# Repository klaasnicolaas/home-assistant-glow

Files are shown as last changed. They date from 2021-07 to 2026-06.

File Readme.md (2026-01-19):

# Home Assistant Glow 🌟

<!-- PROJECT SHIELDS -->

[](LICENSE)
[][forks-url]
[][stars-url]
[][issues-url]

[][commits]
[][commits]
[][contributors-url]

During my internship at [Nabu Casa][nc] in the first half of 2021, I focused on energy management for your house, how to collect all energy data and display it on a dashboard. Since Home Assistant release **2021.8** it's possible to use the [Home Assistant Energy][energy] dashboard to display your energy usage. Unfortunately, not everyone has a smart meter and/or is equipped with a P1 port. This is where the Home Assistant Glow comes in!

<p align="center">
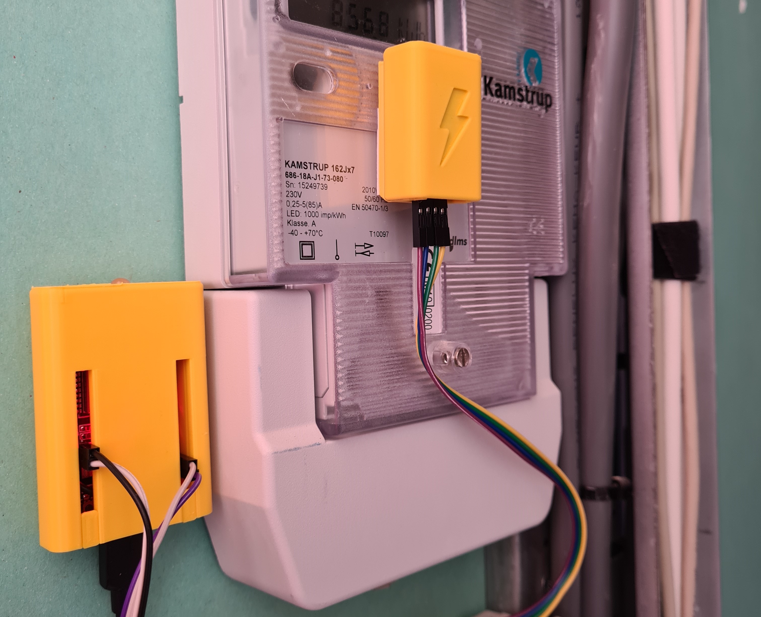
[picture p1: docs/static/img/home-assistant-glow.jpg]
  
</p>

<details>
  <summary>CLICK HERE! To see the Home Assistant Glow in action.</summary>

  <p align="center">
    Glow testingGlow in action
  </p>
</details>

Home Assistant Glow makes a *(not so)* smart meter without a P1 port easily readable, reading the pulse LED that is always present in most cases and it works with [ESPHome][esphome]! To neatly hide it all in your meter cupboard, a case has been designed that you can 3D print yourself.

### How do I know if my meter is supported?

To make sure your meter will work with the Home Assistant Glow, you have to look for the `imp/kWh` rate on your meter (see picture). Make a note of this value because you may need it later when configuring your device.

<p align="center">
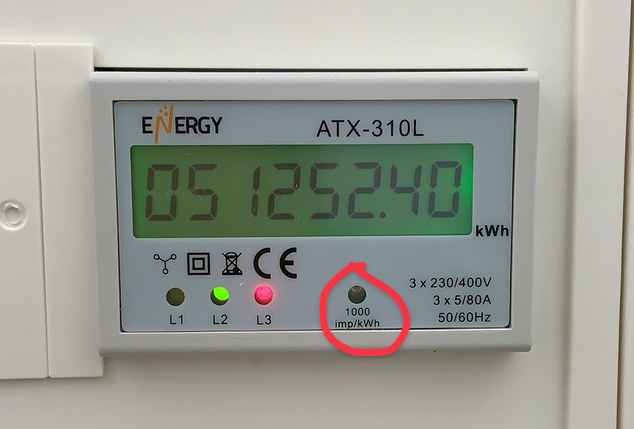
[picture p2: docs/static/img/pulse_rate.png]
  
</p>

## Getting Started

> [!IMPORTANT]
> Please note, the default branch shows development and may be ahead of the released version. For copying YAML code, use the [release branch](https://github.com/klaasnicolaas/home-assistant-glow/releases/latest). It's best to use the [website](https://glow-energy.io/docs/getting-started#step-2---install-firmware) to install the latest firmware on your ESP.

On the [documentation website](https://glow-energy.io/docs/introduction) you will find a complete walkthrough with which hardware you need, how to install the correct firmware on your ESP (using esp web tools) and how to add it to Home Assistant.

## Hardware

First, fill your 🛒 or see if you already have the components below.

Choose one of the listed microcontrollers, but keep in mind that the ESP32 is recommended.

  - ESP32 (recommended) - [AliExpress](https://s.click.aliexpress.com/e/_DdAe4Fl) or [Banggood][esp32-bg-shop] or [AliExpress][esp32-ali-shop]
  - ESP32-C3 - [AliExpress](https://s.click.aliexpress.com/e/_DFNCxYn) or [AliExpress][esp32c3-ali-shop]
  - ESP8266 - [AliExpress](https://s.click.aliexpress.com/e/_omR3PTr) or [Banggood][esp8266-bg-shop] or [AliExpress][esp8266-ali-shop]
- Dupont Jumpers (female to female) - [AliExpress](https://s.click.aliexpress.com/e/_DmbrJsj) or [Banggood][dupont-jumpers-shop]
- 3D-printed case (see the [case](https://glow-energy.io/docs/resources/cases) folder)
- LM393 Photodiode: [AliExpress](https://s.click.aliexpress.com/e/_c3utxSRp) or [Banggood][photodiode-bg-shop] or [AliExpress][photodiode-ali-shop] (please note that you will not receive an LDR)
- LED RGB 5mm 4 pin - kathode: [AliExpress](https://s.click.aliexpress.com/e/_c3H3JVT9) or [Banggood][rgbled-bg-shop] or [AliExpress][rgbled-ali-shop]

## Contributing

We welcome contributions! Please read the [contribution guidelines](CONTRIBUTING.md) before submitting PRs.

Thanks to everyone who already contributed! ❤️

<a href="https://github.com/klaasnicolaas/home-assistant-glow/graphs/contributors">
  
</a>

For a full list of all authors and contributors, check [the contributor's page][contributors-url].

## Disclamer

Affiliate links are used on this repository to support the Home Assistant Glow 🌟 project. Some Ad-blockers might block these links and thus they seem to appear broken. You will have to temporarily disable ad-blocker to open these links.

## License

MIT License

Copyright (c) 2021-2026 Klaas Schoute

Permission is hereby granted, free of charge, to any person obtaining a copy
of this software and associated documentation files (the "Software"), to deal
in the Software without restriction, including without limitation the rights
to use, copy, modify, merge, publish, distribute, sublicense, and/or sell
copies of the Software, and to permit persons to whom the Software is
furnished to do so, subject to the following conditions:

The above copyright notice and this permission notice shall be included in all
copies or substantial portions of the Software.

THE SOFTWARE IS PROVIDED "AS IS", WITHOUT WARRANTY OF ANY KIND, EXPRESS OR
IMPLIED, INCLUDING BUT NOT LIMITED TO THE WARRANTIES OF MERCHANTABILITY,
FITNESS FOR A PARTICULAR PURPOSE AND NONINFRINGEMENT. IN NO EVENT SHALL THE
AUTHORS OR COPYRIGHT HOLDERS BE LIABLE FOR ANY CLAIM, DAMAGES OR OTHER
LIABILITY, WHETHER IN AN ACTION OF CONTRACT, TORT OR OTHERWISE, ARISING FROM,
OUT OF OR IN CONNECTION WITH THE SOFTWARE OR THE USE OR OTHER DEALINGS IN THE
SOFTWARE.

<!-- MARKDOWN LINKS & IMAGES -->
[esphome]: https://esphome.io
[nc]: https://www.nabucasa.com
[energy]: https://www.home-assistant.io/home-energy-management

<!-- Shields -->
[maintenance-shield]: https://img.shields.io/maintenance/yes/2026.svg
[contributors-shield]: https://img.shields.io/github/contributors/klaasnicolaas/home-assistant-glow.svg
[contributors-url]: https://github.com/klaasnicolaas/home-assistant-glow/graphs/contributors
[forks-shield]: https://img.shields.io/github/forks/klaasnicolaas/home-assistant-glow.svg
[forks-url]: https://github.com/klaasnicolaas/home-assistant-glow/network/members
[stars-shield]: https://img.shields.io/github/stars/klaasnicolaas/home-assistant-glow.svg
[stars-url]: https://github.com/klaasnicolaas/home-assistant-glow/stargazers
[issues-shield]: https://img.shields.io/github/issues/klaasnicolaas/home-assistant-glow.svg
[issues-url]: https://github.com/klaasnicolaas/home-assistant-glow/issues
[license-shield]: https://img.shields.io/github/license/klaasnicolaas/home-assistant-glow.svg
[commits-shield]: https://img.shields.io/github/commit-activity/y/klaasnicolaas/home-assistant-glow.svg
[commits]: https://github.com/klaasnicolaas/home-assistant-glow/commits/main
[last-commit-shield]: https://img.shields.io/github/last-commit/klaasnicolaas/home-assistant-glow.svg

<!-- Hardware -->
[esp32-bg-shop]: https://www.banggood.com/bang/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
[esp32-ali-shop]: https://tc.tradetracker.net/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
[esp32c3-ali-shop]: https://tc.tradetracker.net/?c=15640&m=12&a=417111&r=&u=%2Fitem%2F1005006391993583.html
[esp8266-bg-shop]: https://www.banggood.com/bang/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
[esp8266-ali-shop]: https://tc.tradetracker.net/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
[dupont-jumpers-shop]: https://www.banggood.com/bang/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
[photodiode-bg-shop]: https://www.banggood.com/bang/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
[photodiode-ali-shop]: https://tc.tradetracker.net/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
[rgbled-bg-shop]: https://www.banggood.com/bang/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
[rgbled-ali-shop]: https://tc.tradetracker.net/?c=15640&m=12&a=417111&r=&u=%2Fitem%2F4000225253691.html

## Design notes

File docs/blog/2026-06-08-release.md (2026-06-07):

---
slug: release-5.0.0
title: Release 5.0.0
authors: klaas
tags: [glow, release, update]
---

Version 5.0.0 of the Home Assistant Glow is here 🌟! This major release brings a configurable internal filter to reduce ghost pulse detections, alongside a **breaking change**: all entity names have been cleaned up to follow the modern ESPHome naming convention.

<!-- truncate -->

## Entity Name Changes

ESPHome now recommends using bare entity names without a device name prefix. Home Assistant automatically shows entity names in the context of their device, making the prefix redundant. All entities in the Glow firmware have been updated accordingly.

The following entities have been renamed:

| Old name | New name |
|---|---|
| `{device} - Power Consumption` | `Power Consumption` |
| `{device} - Total Energy` | `Total Energy` |
| `{device} - Daily Energy` | `Daily Energy` |
| `{device} - ESPHome Version` | `ESPHome Version` |
| `{device} - IP Address` | `IP Address` |
| `{device} - Connected SSID` | `Connected SSID` |
| `{device} - WiFi Signal` | `WiFi Signal` |
| `Glow - Installed version` | `Installed Version` |
| `Restart - Glow` | `Restart` |

:::warning Breaking change
Renaming entities changes their entity IDs in Home Assistant. After updating, the old entities will show as unavailable and new ones will be created. You will need to update any automation flows, dashboards, or Energy dashboard configurations that reference the old entity IDs.
:::

### Migration Guide

After updating to 5.0.0, take the following steps:

1. Open Home Assistant and go to **Settings > Devices & Services > ESPHome**
2. Open the Glow device page and verify the new entity names appear
3. Remove the unavailable (old) entities via **Settings > Devices & Services**, selecting each old entity and deleting it
4. Update any automation flows or dashboard cards that referenced the old entity IDs
5. If you use the Energy dashboard, re-select the correct entities under **Settings > Energy**

## Configurable Internal Filter

Based on a [community request][issue-983], this release exposes the internal filter of the pulse meter as a configurable entity in Home Assistant. Previously, users experiencing ghost pulses (false detections that cause unrealistic power spikes) had no way to adjust the filter without modifying the firmware directly.

The **Internal Filter** entity appears in the configuration section of the Glow device page in Home Assistant. It accepts values in microseconds (µs), with a default of `1000 µs` (1 ms) and a maximum of `100000 µs` (100 ms). The value is persisted across reboots, so you only need to set it once.

If you are experiencing sudden power spikes in the thousands of kilowatts, try increasing the internal filter value gradually. A value between **1000 µs** and **10000 µs** is a good starting point for most setups.

:::caution
Setting the internal filter too high can cause real pulses to be missed at high power consumption. See the [Internal Filter](/docs/configuration/internal_filter) page for guidance on choosing the right value for your setup.
:::

:::note Upgrade note for advanced users
If you previously used `!extend sensor_energy_pulse_meter` with `internal_filter` in your YAML configuration, this will no longer have any effect. The **Internal Filter** entity always takes precedence after boot. You can remove the `!extend` block and set your desired value via the UI instead.
:::

## Pulse Rate Entity Fix

ESPHome warns that entity names containing `/` are reserved as URL path separators and will become an error in ESPHome 2026.7.0. The **Pulse Rate** entity was previously named `Pulse rate - imp/kWh` and is now simply `Pulse rate`, with `imp/kWh` set as a proper `unit_of_measurement`.

## Upgrading to 5.0.0

**Via Home Assistant**: If your Glow is connected to Home Assistant, you'll receive an update notification automatically. Simply click update from the device page, the easiest option.

**Via the Web Interface (OTA)**: Download the correct firmware binary from the [Firmware Updates](/docs/advanced/firmware_updates) page, open the Glow's web interface, and upload it via the **OTA Update** section.

**Via USB**: Head to the [Getting Started](/docs/getting-started) page, select your variant, and flash via USB.

## Wrap up

This release is a significant step in keeping the Home Assistant Glow aligned with current ESPHome best practices, while also making the firmware easier to use for those dealing with noisy meter environments. The entity renaming requires some manual steps after upgrading, but the result is a cleaner and more consistent device experience in Home Assistant.

If you would like to support the project, you can do so through [GitHub sponsors](https://github.com/sponsors/klaasnicolaas) or Ko-fi. If you have any questions, you can ask them via the [discussions](https://github.com/klaasnicolaas/home-assistant-glow/discussions), and if you encounter problems with the Home Assistant Glow, you can indicate this in the [issues](https://github.com/klaasnicolaas/home-assistant-glow/issues).

./Klaas



## Related links

- [Internal Filter Configuration](/docs/configuration/internal_filter)
- [FAQ: Unrealistic power spikes](/docs/faq/ghost_pulses)
- [Customizing the Firmware](/docs/advanced/firmware_changes)
- [Firmware Updates](/docs/advanced/firmware_updates)

<!-- Links -->
[issue-983]: https://github.com/klaasnicolaas/home-assistant-glow/issues/983

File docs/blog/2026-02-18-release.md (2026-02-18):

---
slug: release-4.4.0
title: Release 4.4.0
authors: klaas
tags: [glow, release, update]
---

Version 4.4.0 of the Home Assistant Glow is here 🌟! The highlight of this release is the **Glow Basic** variant, a firmware for setups without LED hardware, alongside improved GitHub Actions workflows and a refreshed documentation experience.

<!-- truncate -->

## Glow Basic Variant

Based on a [community request][discussion-910], this release introduces **Glow Basic**: a firmware variant without LED support. For setups where the Glow sits in a closed meter cabinet or where the LED hardware simply isn't wired up, there was no clean way to run the firmware without unnecessary LED-related log entries. Glow Basic solves that.

- **Lighter firmware**: No LED components are included, resulting in a smaller and simpler build
- **Separate device identity**: Shows up as `Glow Basic` in Home Assistant, making it easy to distinguish from the standard variant
- **Same core functionality**: Pulse meter, energy tracking, OTA updates, and web server all work the same

Available for all three supported boards: ESP32, ESP32-C3, and ESP8266.

### Choosing Your Variant

The [Getting Started](/docs/getting-started) page now features an interactive firmware selector to pick between **Standard** and **Basic** before flashing your device.

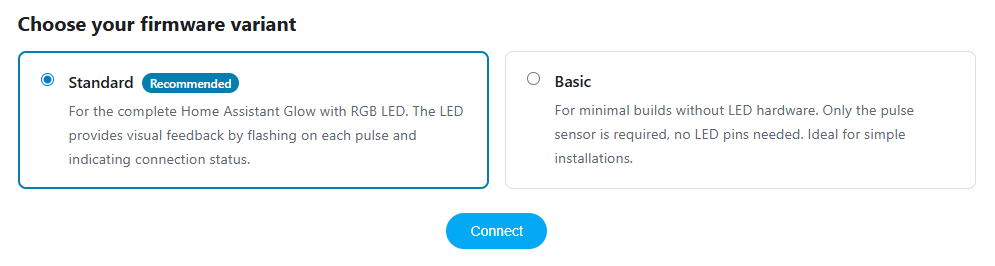
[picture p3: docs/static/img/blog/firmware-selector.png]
Firmware Selector


## Improved Build & Deploy Workflows

The GitHub Actions workflows have been updated to support both firmware variants through a matrix build strategy:

- **Matrix builds**: Each pull request and release now builds firmware for all device and variant combinations in parallel
- **Organized artifacts**: Build artifacts follow a clear naming scheme (`build-glow-standard-esp32`, `build-glow-basic-esp32c3`, etc.)
- **PR download table**: Pull request comments now include a table with download links for both variants, making it easy to test firmware from any PR

## Documentation Improvements

The getting started guide received a visual overhaul:

- **Step badges**: Each step now has a numbered badge for clearer visual guidance
- **Firmware selector component**: An interactive radio button card to choose between Standard and Basic before connecting
- **Tabbed connection options**: Step 3 now uses tabs to present the different connection methods (auto-discovery vs manual configuration)

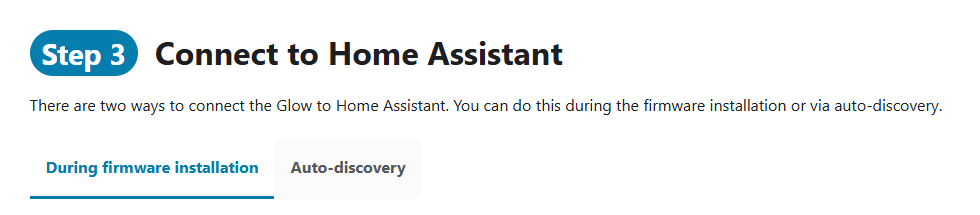
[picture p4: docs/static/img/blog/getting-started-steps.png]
Getting Started


## Upgrading to 4.4.0

There are several ways to update your Glow to the latest version:

- **Via Home Assistant**: If your Glow is connected to Home Assistant, you'll receive an update notification automatically. Simply click update from the device page — the easiest option.
- **Via the Web Interface (OTA)**: Download the correct firmware binary from the [Firmware Updates](/docs/advanced/firmware_updates) page, open the Glow's web interface, and upload it via the **OTA Update** section.
- **Via USB**: Head to the [Getting Started](/docs/getting-started) page, select your variant, and flash via USB.

:::tip Switching variants
You can switch from Standard to Basic (or vice versa) by simply flashing the other variant. Your Wi-Fi credentials and Home Assistant connection will be preserved.
:::

## Wrap up

This release makes the Home Assistant Glow more accessible by offering a basic variant for builds without LED hardware, while improving the development workflow and documentation along the way.

If you would like to support the project, you can do so through [GitHub sponsors](https://github.com/sponsors/klaasnicolaas) or Ko-fi. If you have any questions, you can ask them via the [discussions](https://github.com/klaasnicolaas/home-assistant-glow/discussions), and if you encounter problems with the Home Assistant Glow, you can indicate this in the [issues](https://github.com/klaasnicolaas/home-assistant-glow/issues).

./Klaas



## Related links

- [Getting Started Guide](/docs/getting-started)
- [Firmware Updates](/docs/advanced/firmware_updates)
- [Customizing the Firmware](/docs/advanced/firmware_changes)

<!-- Links -->
[discussion-910]: https://github.com/klaasnicolaas/home-assistant-glow/discussions/910

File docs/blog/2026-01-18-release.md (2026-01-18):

---
slug: release-4.3.0
title: Release 4.3.0
authors: klaas
tags: [glow, release, update]
---

I'm excited to announce the release of version 4.3.0 of the Home Assistant Glow 🌟. This release brings support for the ESP32-C3 board, enhanced ESP32 configurations, comprehensive documentation improvements, and a refined development workflow with linting.

<!-- truncate -->

## ESP32-C3 Support

The Home Assistant Glow now officially supports the ESP32-C3 board! This compact and energy-efficient variant of the ESP32 family is now available as a configuration option.

If you're building your own Glow or looking to upgrade, the ESP32-C3 is now a fully supported option alongside the existing ESP32 and ESP8266 boards.

:::tip 3D Case Designs Welcome
If you've designed a 3D-printed case for the ESP32-C3 variant, we'd love to add it to our [3D Cases resource page](/docs/resources/cases)! Feel free to share your design via a [discussion](https://github.com/klaasnicolaas/home-assistant-glow/discussions) or [pull request](https://github.com/klaasnicolaas/home-assistant-glow/pulls).
:::

## ESP32 Configuration Updates

The ESP32 configuration has received significant improvements in this release:

- **ESP-IDF Framework**: The ESP32 build now uses the esp-idf framework instead of arduino, providing better performance and more stability
- **Board Variant Support**: Proper board variant configuration has been added for better hardware compatibility

These changes ensure that your ESP32-based Glow device runs more efficiently and reliably.

## Documentation Overhaul

We've made extensive improvements to the documentation to help you get the most out of your Glow device:

### New Content

- **Reverting to Default Firmware**: Complete guide on how to return to the default firmware if you've adopted your device in ESPHome Builder
- **Finding Component IDs**: Documentation listing commonly used component IDs (like `sensor_energy_pulse_meter`, `status_led`, `ota_esphome`) to help you customize your device
- **Avoiding Encryption Key Issues**: New FAQ section explaining when to stick with default firmware vs. when to adopt in ESPHome Builder

### Improved Page Structure

The documentation structure has been refined to make it easier to find the information you need:

- **Getting Started**: Streamlined onboarding process with clearer step-by-step instructions
- **Advanced Sections**: Firmware updates and customization guides now have better organization with dedicated sections for different use cases
- **FAQ Pages**: Updated with practical solutions and cross-references to related documentation

## Pulse Rate Configuration

The pulse rate configuration has been adjusted for better usability:
- Minimum value changed to 10 (from lower values)
- Step size set to 10 for easier selection

This makes it simpler to configure the pulse rate for common energy meters.

## Wrap up

This release focuses on expanding hardware support and making the documentation more accessible and helpful. Whether you're setting up a new Glow device or customizing an existing one, the improved documentation should make the process much smoother.

If you would like to support the project, you can do so through [GitHub sponsors](https://github.com/sponsors/klaasnicolaas) or Ko-fi. If you have any questions, you can ask them via the [discussions](https://github.com/klaasnicolaas/home-assistant-glow/discussions), and if you encounter problems with the Home Assistant Glow, you can indicate this in the [issues](https://github.com/klaasnicolaas/home-assistant-glow/issues).

./Klaas



## Related links

- [Customizing the Firmware](/docs/advanced/firmware_changes)
- [FAQ: Encryption Key Required](/docs/faq/encryption_key_required)
- [Getting Started Guide](/docs/getting-started)

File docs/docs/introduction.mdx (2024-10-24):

---
id: introduction
title: Introduction
description: What is the Home Assistant Glow?s
---

# Introduction

During my internship at [Nabu Casa](https://www.nabucasa.com) in the first half of 2021, I focused on energy management for your house, how to collect all energy data and display it on a dashboard. Since Home Assistant release **2021.8** it's possible to use the [Home Assistant Energy](https://www.home-assistant.io/home-energy-management) dashboard to display your energy usage. Unfortunately, not everyone has a smart meter and/or is equipped with a P1 port. This is where the Home Assistant Glow comes in!

## What does it do?

Home Assistant Glow makes a (not so) smart meter without a P1 port easily readable, using the pulse LED that is always present in most cases and it works with [ESPHome](https://esphome.io)! To neatly hide it all in your meter cupboard, a case has been designed that you can 3D print yourself.

<p align="center">
  
</p>

## How do I know if my meter is supported?

To make sure your meter will work with the Home Assistant Glow, you have to look for the `imp/kWh` rate on your meter (see picture). Make a note of this value because you may need it later when configuring your device.

<p align="center">
  
</p>

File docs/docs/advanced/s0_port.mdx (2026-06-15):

---
id: s0_port
title: Using an S0 Port
description: Learn how to connect and configure the Home Assistant Glow with an S0 pulse output instead of an optical sensor.
---

# Using an S0 Port

The Home Assistant Glow is primarily designed to read the **optical pulse LED** on your electricity meter. However, some meters (particularly industrial or three-phase meters) do not have a visible pulse LED but instead provide an **S0 port** (defined in IEC 62053-31). This page explains how to connect the Glow to an S0 port and what to keep in mind.

:::caution
S0 port support is not a primary use case of the Home Assistant Glow. The hardware and default settings are optimised for optical pulse detection. The steps below describe a community-supported approach that requires some manual configuration.
:::

## What is an S0 Port?

An S0 port is an open-collector (or open-drain) pulse output. Each pulse represents a fixed amount of energy consumed, for example one pulse per Wh at 1000 imp/kWh. The port works by briefly pulling the signal line LOW for at least 30 ms, then releasing it.

Key S0 specifications (IEC 62053-31):

| Parameter | Minimum |
|---|---|
| Pulse ON time (LOW) | 30 ms |
| Pulse OFF time (HIGH) | 30 ms |

## Wiring

To connect an S0 port to the Glow, you need an external **pull-up resistor** between the pulse pin and 3.3 V, because the S0 output can only pull the line LOW and cannot drive it HIGH.

Connect the wires as follows:

| S0 Terminal | ESP32 | ESP32-C3 | ESP8266 |
|---|---|---|---|
| S0+ | GPIO26 | GPIO10 | GPIO13 |
| S0- | GND | GND | GND |

Add a **4.7 kΩ to 10 kΩ** pull-up resistor between the pulse input pin and 3.3 V. A lower resistance (e.g. 4.7 kΩ) provides better noise immunity on longer cable runs.

:::important
The ESP32, ESP32-C3, and ESP8266 all use 3.3 V logic levels. Never connect an S0 port that operates at 5 V or higher directly to a GPIO pin.
:::

## Adjusting the Internal Filter

S0 connections can be susceptible to electrical noise, particularly with long cable runs or nearby switching equipment. With the default internal filter of **1000 µs** (1 ms), noise spikes between 1 ms and 30 ms can be counted as valid pulses, causing the total energy reading to drift higher than the actual meter over time.

To reduce this effect, increase the internal filter. The internal filter defines the minimum time the signal must be active (LOW) before it is counted as a valid pulse. Per IEC 62053-31, the minimum S0 pulse ON time is 30 ms, so any filter value above that risks dropping valid pulses depending on your meter.

A value of **50000 µs** (50 ms) has been reported to produce accurate readings in practice, but this depends on your meter sending pulses longer than 50 ms. If you notice pulses being missed, lower the filter and check your meter's documentation for the actual pulse duration.

See the [Internal Filter](/docs/configuration/internal_filter) page for instructions on how to change this value.

## Troubleshooting

**Total energy reads higher than the actual meter**

This is the most common issue with S0 connections and is caused by electrical noise being counted as extra pulses. Increase the internal filter value. A value of 50000 µs (50 ms) has been reported to work well for S0 connections.

**No pulses detected**

- Check that the pull-up resistor is connected between the pulse pin and 3.3 V.
- Verify the S0 polarity: S0+ to the pulse pin and S0- to GND.
- Make sure the internal filter is not set higher than the minimum pulse ON time of your meter.

**Power consumption reads incorrectly**

Verify that the [pulse rate](/docs/configuration/pulse_rate) matches the imp/kWh value printed on your meter.

## Useful Resources

- [Adjust the Internal Filter](/docs/configuration/internal_filter)
- [Adjust the Pulse Rate](/docs/configuration/pulse_rate)
- [ESPHome Pulse Meter documentation](https://esphome.io/components/sensor/pulse_meter.html)

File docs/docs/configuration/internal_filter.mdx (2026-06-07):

---
id: internal_filter
title: Internal Filter
description: Learn how to adjust the internal filter of your Home Assistant Glow device to reduce ghost detections.
---

# Adjust the Internal Filter

The Glow uses a pulse meter to track energy usage. In some situations, electrical noise or reflections near the meter's LED can cause false pulse detections, also known as **ghost pulses**. These show up as unrealistic power spikes (e.g. 1000 kW) in Home Assistant.

The internal filter defines the minimum duration (in microseconds) a signal must be active before it is counted as a valid pulse. Increasing this value filters out short noise pulses, reducing ghost detections.

The Glow defaults to `1000` **µs** (1 ms). If you are experiencing ghost detections, try increasing this value gradually.

:::caution
Setting the internal filter too high can cause real pulses to be missed, especially at high power consumption or with meters that have a high imp/kWh rate. A value up to **10000 µs** (10 ms) is a good starting point for most residential setups.
:::

You can adjust the value in 2 ways:

### Option 1: Via the web interface

Open the web server by going to the IP address of your Home Assistant Glow, where you will find the line **Internal Filter** in the table, and you can adjust it on the right.

### Option 2: In Home Assistant

1. Go to the device overview page of the Home Assistant Glow, via [**Settings** > **Devices & Services** > **ESPHome**](https://my.home-assistant.io/redirect/integration/?domain=esphome).
2. Adjust the value for the entity **Internal Filter** under the configuration section.

:::note
Since the internal filter is now controlled at runtime via the **Internal Filter** entity, overriding `internal_filter` directly on the pulse meter sensor in your YAML configuration will no longer work. The entity value always takes precedence after boot. Use one of the two options above instead.
:::

## Useful resources

- [Glow Energy - FAQ page](/docs/faq)
- [ESPHome Pulse Meter documentation](https://esphome.io/components/sensor/pulse_meter.html)

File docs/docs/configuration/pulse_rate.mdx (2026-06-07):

---
id: pulse_rate
title: Pulse Rate
description: Learn how to adjust the pulse rate of your Home Assistant Glow device to match your energy meter.
---

# Adjust the Pulse Rate

The Glow uses a pulse meter to track energy usage, which requires setting the correct pulse rate to match your energy meter. This ensures accurate energy monitoring and tracking in Home Assistant.

In most cases, the correct pulse rate is set during the [getting started](/docs/getting-started#step-4-configure-the-pulse-rate) guide, but you can easily adjust it later if needed. If the pulse rate hasn't been changed yet, the Glow defaults to `1000` **imp/kWh**, which is commonly used in the Netherlands. However, you may need to modify this value based on your energy meter's specifications.

You can adjust the value in 2 ways:

### Option 1: Via the web interface

You open the web server by going to the IP address of your Home Assistant Glow, where you will find the line **Pulse rate** in the table, and you can then adjust it on the right.

<p align="left">
  Adjusting the pulse rate via the web interface
</p>

### Option 2: In Home Assistant

1. Go to the device overview page of the Home Assistant Glow, via [**Settings** > **Devices & Services** > **ESPHome**](https://my.home-assistant.io/redirect/integration/?domain=esphome).
2. Adjust the value for the entity **Pulse rate**.

## Useful resources

- [Glow Energy - FAQ page](/docs/faq)

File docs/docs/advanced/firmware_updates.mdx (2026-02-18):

---
id: firmware_updates
title: Firmware Updates
description: Learn how to update the firmware of the Glow.
---

# Firmware Updates

Keeping your device's firmware up to date is essential to ensure it runs smoothly and benefits from the latest (ESPHome) features. This guide will walk you through how to update the firmware of the Home Assistant Glow.

## Updating Firmware through Home Assistant

_Level of Difficulty: **Easy**_

The easiest way to update the firmware of the Glow is through Home Assistant. When a new firmware update is available, you will receive a notification directly within Home Assistant. To update your device, follow these simple steps:

1. Look on the **Settings** page of Home Assistant for update notifications.
2. Click on the notification for the Home Assistant Glow.
3. A pop-up will appear with release notes / version number and the option to update the firmware.
4. Click **Install** to start the process.

<p align="left">
  Update notification in Home Assistant
</p>

:::note
Since ESPHome 2024.6.x, the update component can directly retrieve firmware updates from the [glow-energy.io](https://glow-energy.io) manifest. Which has made updating even easier and eliminates the need to use ESPHome Builder (app) just for updates.
:::

## Glow Web Interface

_Level of Difficulty: **Medium**_

If you are unable to update the firmware through Home Assistant, you can also update the firmware directly within the Glow's web interface. This method is useful if you are using the Glow as a standalone device or if you prefer to update the firmware manually.

1. Download the latest firmware binary file for your device:

    **Which variant do you need?**

    Choose the variant that matches your hardware setup:

    - **Standard** - For the complete Home Assistant Glow with RGB LED (recommended for most users)
    - **Basic** - For minimal builds without LED hardware (only pulse sensor connected)

    | Device | Standard | Basic |
    |--------|---------|-------|
    | **ESP32** | [Download](https://glow-energy.io/home-assistant-glow/esp32/home-assistant-glow-esp32.ota.bin) | [Download](https://glow-energy.io/glow-basic/esp32/glow-basic-esp32.ota.bin) |
    | **ESP32-C3** | [Download](https://glow-energy.io/home-assistant-glow/esp32c3/home-assistant-glow-esp32c3.ota.bin) | [Download](https://glow-energy.io/glow-basic/esp32c3/glow-basic-esp32c3.ota.bin) |
    | **ESP8266** | [Download](https://glow-energy.io/home-assistant-glow/esp8266/home-assistant-glow-esp8266.ota.bin) | [Download](https://glow-energy.io/glow-basic/esp8266/glow-basic-esp8266.ota.bin) |
2. Navigate to the Glow's web interface, by entering the IP address of the device in your browser.
3. At the bottom of the page, you will find the **OTA Update** section.
4. Click on **Choose File** and select the firmware binary file you downloaded.
5. Click **Upload** to start the update process.

After the update is complete, the device will automatically reboot with the new firmware.

## ESPHome Builder

_Level of Difficulty: **Advanced**_

If you are using the ESPHome Builder app in Home Assistant, you can also update the firmware through the dashboard. This method is useful if you have adopted the firmware to your ESPHome Builder and know how to tweak the YAML configuration.

:::warning
Once you adopt a device in ESPHome Builder, you will no longer receive automatic firmware updates from [glow-energy.io](https://glow-energy.io). You will need to manage all firmware updates yourself through ESPHome Builder.
:::

1. Open the ESPHome Builder (app).
2. If it is possible to update the firmware, you will see an update button at the device card (see image below).
3. Click on the **UPDATE** button to start the process.
4. Select **Wirelessly** to update the firmware over-the-air (OTA).
5. It will start the update process, and you will see the update process in a pop-up window.

Once the update is complete, the device will automatically reboot with the new firmware.

<p align="left">
  Update firmware through ESPHome Builder (app)
</p>

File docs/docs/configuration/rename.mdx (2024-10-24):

---
id: rename
title: Rename the Glow
description: Learn how to rename your Home Assistant Glow device to something more descriptive and user-friendly.
---

# Rename your Glow in Home Assistant

When you add the Glow to Home Assistant, it is automatically given a default name like `home-assistant-glow-XXXXXX`, where `XXXXXX` is a portion of the device's MAC address. This name shows up in the device list, but it isn't very descriptive. Renaming the device makes it much easier to manage, and if you want, you can also update the **entity IDs** to match the new device name for consistency.

## Why rename the device?

Even though the entity IDs don't include the MAC address and are functional as they are, having a device name that includes part of the MAC address isn't ideal. Changing the device name to something more descriptive can help you:

- Quickly identify the device in Home Assistant.
- Make it easier to work with the device when adding in automations or dashboards.
- Keep your Home Assistant setup organized and clear 🧹

## Step-by-step guide to rename your Glow

Here's how to change the name of your Glow in Home Assistant:

1. Open your Home Assistant dashboard/interface.
2. **Go to settings**: From the sidebar, click on **Settings** and then select **Devices & Services**.
3. In the **ESPHome** section, find your glow. If you have multiple devices, look for the one with the default format.

  **Pro Tip**: Want to get there faster? Click the badge below to jump directly to your device page:

[][esphome-devices]

4. On the device details page, click the pencil icon in the top-right corner to rename it (see image below).
5. **Choose a descriptive name** that's easy to remember, like "Home Assistant Glow" or "Glow Energy".
6. Click **Update** to save the new name.

<p align="left">
  Renaming a device in Home Assistant
</p>

### Renaming Entity IDs (Optional)

After you rename the device, Home Assistant may ask if you want to also rename the associated entity IDs. The entity IDs are already usable as is, but if you prefer consistency, you can rename them to match the new device name:

- **If you want the entity IDs to stay the same**: Simply keep the existing entity IDs and only update the device name.
- **Want everything to be consistent?** You can rename the entity IDs too, but be aware that this is a breaking change. You will need to update all automations, scripts, dashboards, and any other configurations that reference the old entity IDs to prevent disruptions in your Home Assistant setup.

## Helpful resources

- [Home Assistant - Terminology](https://home-assistant.io/getting-started/concepts-terminology)

[esphome-devices]: https://my.home-assistant.io/redirect/integration/?domain=esphome

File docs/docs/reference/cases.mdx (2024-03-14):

---
id: cases
title: Cases
description: Collection of all cases that you can 3D print
---

# Cases

On this page you will find all the cases that you can 3D print for the Home Assistant Glow. If you've made some changes on the cases, I'd appreciate it if you add the new case design to the repository for everyone to benefit 😉

## Photodiode PCB

<p align="left">
  
</p>

This case consists of 2 parts, a top and bottom where you can slide the parts over each other. If you would like to make adjustments to the original design, you can download and use the [STEP](/cases/Home_Assistant_Glow.step) file.

| Name | Description | ⬇️ |
| ---- | --- | -- |
| Sensor - Top | Top part of the case for the sensor | [Download](/cases/Photodiode_PCB/Sensor_top_side_v1.stl)
| Sensor - Bottom | Bottom part of the case for the sensor | [Download](/cases/Photodiode_PCB/Sensor_bottom_side_v1.stl)

The photodiode case files are also available on [Printables](https://www.printables.com/model/785966-home-assistant-glow).

## ESP32S

<p align="left">
  
</p>

This case consists of 2 parts, a top and bottom where you can slide the parts over each other. In a way that leaves room for the Dupont jumper cables. If you would like to make adjustments to the original design, you can download and use the [STEP](/cases/Home_Assistant_Glow.step) file.

| Name | Description | ⬇️ |
| ---- | --- | -- |
| ESP32S - Top | Top part of the case for the ESP32S | [Download](/cases/ESP32S/ESP32_top_side_v1.stl)
| ESP32S - Bottom | Bottom part of the case for the ESP32S | [Download](/cases/ESP32S/ESP32_bottom_side_v1.stl)

The ESP32S case files are also available on [Printables](https://www.printables.com/model/785966-home-assistant-glow).

## ESP32-WROOM-32D

<p align="left">
  
  
</p>

This case consists of 2 parts, a top and bottom where you can friction fit the pieces over each other and is designed to be used in both an indoor and outdoor environment. The LED status light is designed to slide into the housing and form a relatively tight seal. The USB cable is designed to slide up to provide some protection to water intrusion.

If you're familiar with OnShape, you can access the model using [this link](https://cad.onshape.com/documents/28a914bca0ab451bdef13eb6/w/61ae11d2b0e90a508761a159/e/b81866b90bb3011f3cadb1f2). Simply make a copy and customize it according to your specifications. Please note that having an account might be necessary to make adjustments.

| Name | Description | ⬇️ |
| ---- | --- | -- |
| ESP32 WROOM - Top | Top part of the case for the ESP32D | [Download](/cases/ESP32-WROOM-32D/ESP32-WROOM-32D_top_case.stl)
| ESP32 WROOM - Bottom | Bottom part of the case for the ESP32D | [Download](/cases/ESP32-WROOM-32D/ESP32-WROOM-32D_bottom_case.stl)

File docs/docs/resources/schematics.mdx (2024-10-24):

---
id: schematics
title: Schematics
description: How to connect the Photodiode and Status LED based on wiring diagram
---

# Schematics

In this section, you will find the wiring diagram of how to connect the Photodiode and Status LED to the ESP board of your choice.

## Wiring diagram

Below you will find a wiring diagram of how everything is connected, depending on the type of board you use, the [GPIO pins](/docs/resources/gpio) may be in a different place. You could also omit the status LED if desired.

<p align="center">
  Wiring diagram showing connections between Photodiode, Status LED, and ESP board
</p>

:::important
Please note that there are different boards in circulation and that the GPIO
pins may be on a different location than in the example above. So always double
check and, if necessary, consult the pin layout of your specific board.
:::

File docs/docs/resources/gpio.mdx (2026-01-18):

---
id: gpio
title: GPIO Pinout
description: GPIO pinout of the ESP32, ESP32-C3 and ESP8266 boards
---

# GPIO Pinout

In this section, you will find the GPIO pinout of the ESP32, ESP32-C3 and ESP8266 boards. The GPIO pins are used to connect the Photodiode and Status LED to the ESP board of your choice.

## Photodiode

How the Photodiode is connected to the ESP board of your choice.

| PHOTODIODE | ESP32 | ESP32-C3 | ESP8266 |
|---|---|---|---|
| A0 | NOT USING | NOT USING | NOT USING |
| DO | D26 (GPIO26) | D10 (GPIO10) | D7 (GPIO13) |
| VCC | 3V3 | 3V3 | 3V3 |
| GND | GND | GND | GND |

## Status LED

How the status LED is connected to the ESP board of your choice. For each measured pulse, the LED will briefly flash <span style={{ color: 'red' }}>*red*</span> and in case of no WiFi connection, the LED will continue to flash <span style={{ color: 'blue' }}>*blue*</span>.

| LED | ESP32 | ESP32-C3 | ESP8266 |
|---|---|---|---|
| RED | D2 (GPIO2) | D0 (GPIO0) | D4 (GPIO2) |
| GREEN  | D4 (GPIO4) | D1 (GPIO1) | D2 (GPIO4) |
| BLUE | D5 (GPIO5) | D3 (GPIO3) | D1 (GPIO5) |
| GND | GND | GND | GND |

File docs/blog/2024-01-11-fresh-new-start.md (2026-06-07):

---
slug: fresh-new-start
title: Let's do a fresh new start!
authors: klaas
tags: [glow, new, update]
---

The Home Assistant Glow 🌟 has been around for almost 2.5 years now (Jul 28, 2021) and still there is a lot of interest in the project 🙏🏻 (as can be seen from the number of repository stars).

Star History Chart (https://star-history.com/#klaasnicolaas/home-assistant-glow)
<!-- truncate -->

However, over the past year and a half I've paid little attention to the project, simply because I was too busy studying to become a UX Engineer. Now that I have (almost) graduated, I've a lot more time to spend on the project again and I immediately started working on a refactor of the repository.

## Why a refactor?

In the past I've made a number of choices that have actually made maintaining a small project like the Home Assistant Glow too complex (in my opinion). In addition, I was not satisfied with the documentation and wanted to add more structure in the project.

## What has changed?

TL;DR - A lot 😅 ... v4.0.0 has been released, the most important changes are listed below.

### Breaking changes

1. The pulse meter pin for ESP32 boards has been changed from GPIO `13` to GPIO `26`.
2. The `home_assistant_glow.yaml` file no longer exists.

This would break the **package_import** for existing configs for people in the ESPHome Builder (app). If you would like to use the latest version, I recommend re-flashing your ESP according to step 2 in [Getting Started](/docs/getting-started#step-2-install-firmware), and if desired, [re-adopting](/docs/advanced/firmware_changes#adopting-the-device) your device again in ESPHome Builder (app).

### New config structure

_Relates to point 2 in the breaking changes._

The configuration YAML for the Home Assistant Glow is now split into multiple files. This makes building the firmware per board type easier without a lot of code duplication.

### Documentation website

The previous website has been replaced with a comprehensive documentation website, accessible at [https://glow-energy.io](https://glow-energy.io). This new website is built using [Docusaurus](https://docusaurus.io/), a static site generator widely used by various open source projects and hosted on GitHub Pages. It provides more space to present information in a structured format. Additionally, users can conveniently install firmware on their ESP directly from their browser using [ESP web tools](https://esphome.github.io/esp-web-tools/).

### Configuration in UI

This feature was already present in the old development branch, but never included in a release. From now on, you set the **imp/kWh** rate via an input field in the device UI or via an entity in Home Assistant.

### Building the firmware

The firmware building process has undergone a significant rewrite, allowing the generation of firmware files tailored to various board types. These files are used in the [Getting Started](/docs/getting-started#step-2-install-firmware) section by ESP web tools.

Moving forward, firmware builds will be tested on a weekly basis. This ensures that build problems with latest versions of ESPHome are identified more quickly, providing new users with up-to-date features and improvements in the future.

---

That's it! If you would like to support the project you can do so through [Github sponsors](https://github.com/sponsors/klaasnicolaas) or Ko-fi. If you have any questions, you can ask them via the [discussions](https://github.com/klaasnicolaas/home-assistant-glow/discussions) and if you encounter problems with the Home Assistant Glow, you can indicate this in the [issues](https://github.com/klaasnicolaas/home-assistant-glow/issues).

./Klaas



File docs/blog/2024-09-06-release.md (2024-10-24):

---
slug: release-4.2.0
title: Release 4.2.0
authors: klaas
tags: [glow, release, update]
---

I'm excited to announce the release of version 4.2.0 of the Home Assistant Glow 🌟. It's a small release this time, built on the latest version of ESPHome (2024.8.x) and contains mostly dependency updates for Docusaurus.

<!-- truncate -->

## Moved to Web Server layout V3

The Home Assistant Glow has been upgraded to version 3 of the [web server][webserver] component. This latest version features a fresh design that is more user-friendly and responsive. You can now double-click on tabs to enlarge them, and the layout is optimized for a better mobile experience.

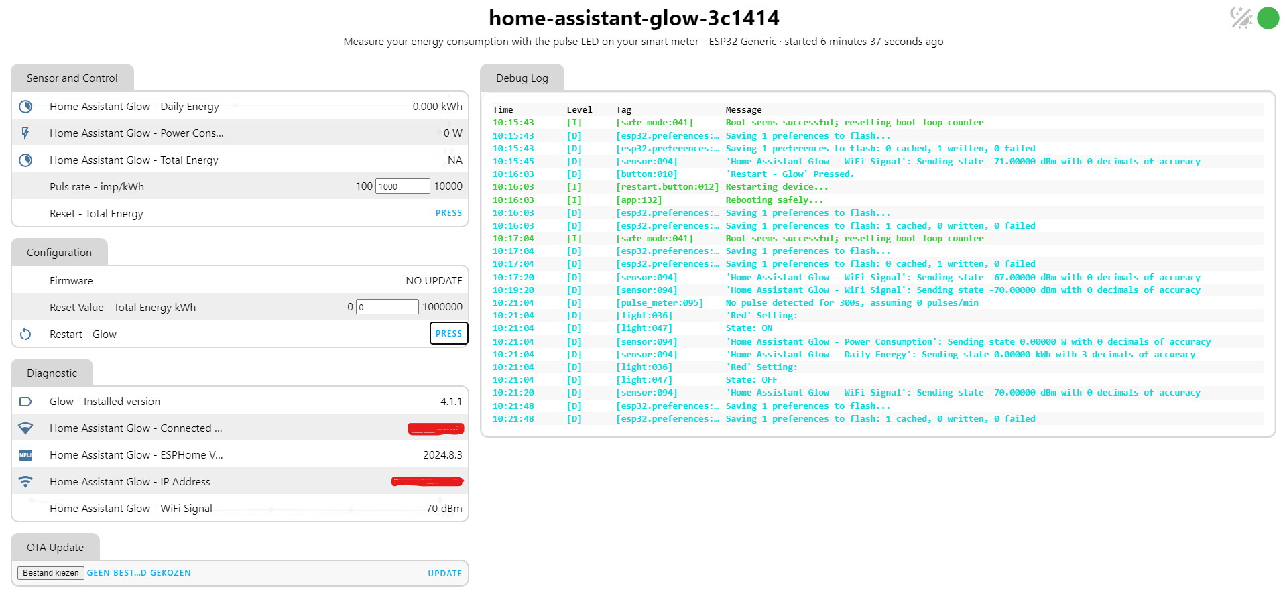
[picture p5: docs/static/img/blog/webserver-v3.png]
Web Server - version 3


:::note
If you don't like the new layout, you can override the web server version in your configuration by using [!extend]. For example, to use the old layout, you can use the following configuration:

```yaml title="your_glow_config.yaml"
web_server:
  - id: !extend esphome_web_server
    version: 2
```
:::

## Wrap up

If you would like to support the project, you can do so through [GitHub sponsors](https://github.com/sponsors/klaasnicolaas) or Ko-fi. If you have any questions, you can ask them via the [discussions](https://github.com/klaasnicolaas/home-assistant-glow/discussions), and if you encounter problems with the Home Assistant Glow, you can indicate this in the [issues](https://github.com/klaasnicolaas/home-assistant-glow/issues).

./Klaas



## Related links

- [ESPHome 2024.8.x - Changelog][esphome-changelog]
- [ESPHome - Extend][!extend]
- [Customizing the Firmware](/docs/advanced/firmware_changes)

<!-- Links -->
[esphome-changelog]: https://esphome.io/changelog/2024.8.0.html
[webserver]: https://esphome.io/components/web_server.html
[!extend]: https://esphome.io/components/packages.html#extend

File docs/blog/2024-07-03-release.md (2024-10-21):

---
slug: release-4.1.0
title: Release 4.1.0
authors: klaas
tags: [glow, release, update]
---

I'm happy to announce the release of version 4.1.0 of the Home Assistant Glow 🌟. This release contains several new features, improvements, and explanations of organizational changes in the repository. In this blog post, I will highlight the most important changes.

<!-- truncate -->

## Milestone on Github

At the beginning of June 2024, the Home Assistant Glow project reached a significant milestone on GitHub: the project has been starred 🌟 over 1000 times. This is a great achievement, and I want to thank everyone who is using the Glow and supporting the project 🚀.

Star History Chart (https://star-history.com/#klaasnicolaas/home-assistant-glow)

## ESPHome OTA updates

With the [ESPHome 2024.6](https://esphome.io/changelog/2024.6.0.html) release, adjustments have been made to the OTA (Over-the-Air) component. This new release provides full support for these updates in the Home Assistant Glow. Along with necessary adjustments due to breaking changes, there is now support for the [http_request] OTA platform. In combination with [Home Assistant 2024.7](https://www.home-assistant.io/blog/2024/07/03/release-20247/#esphome-update-entities-for-ready-made-projects), you can now update your Glow in Home Assistant without the need to build, adopt, or set up the ESPHome software.

:::caution
If you experience problems updating your glow, I recommend re-flashing your ESP via the website.
:::

## Git strategy

_This is a bit of a technical story, but I think it's important to share._

### GitHub flow

The repository has been using a [GitHub flow][github_flow] strategy for a while now. This means that the `main` branch is always deployable, and new features are developed in feature branches. When a feature is ready, it is merged into the `main` branch, and a new release is created.

However, I recently concluded that this strategy does not work well for this project. Mainly due to the use of (external) [packages] and retrieving files from a specific branch or release tag (with `ref`). This may cause you to accidentally fetch development code during a firmware build that may not yet be ready for a release.

### Git flow

To solve this, I've decided to switch to a [Git flow][git_flow] strategy. This means that the `main` branch is always deployable, and new features are developed in feature branches. When a feature is ready, it is merged into the `develop` branch. When a release is ready, the `develop` branch is merged into the `main` branch, and a new release is created.

This strategy allows for a better separation between production and development code and immediately solves the problem with the `ref` of [packages].

:::important
The **default branch** of the repository has also been changed to `develop`. If you are used to copying the YAML code instead of using ESP web tools, pay attention to which branch you do this from (use the `main` branch or latest release).
:::

## Continuous integration

_This is also a bit of a technical story, but interesting for others who have a similar ESPHome project._

With the switch to the [Git flow][git_flow] strategy, I also took the opportunity to improve the continuous integration (CI) of the repository. I split the existing GitHub action workflow into two separate workflows:

- [**Testing / build workflow**][build_workflow]: This workflow is triggered on push from develop or feature branches. It builds the firmware for all devices and checks if the firmware builds are successful.
- [**Deployment workflow**][deploy_workflow]: This workflow is triggered when a new release is created. It deploys the firmware files to the website.

This separation ensures that the firmware files on the website are always the same as the release on GitHub. What's extra nice is that the deployment workflow reuses the testing workflow to build the firmware files.

## Wrap up

This release contains some nice features / improvements that make the Home Assistant Glow more 🌟

If you would like to support the project, you can do so through [GitHub sponsors](https://github.com/sponsors/klaasnicolaas) or Ko-fi. If you have any questions, you can ask them via the [discussions](https://github.com/klaasnicolaas/home-assistant-glow/discussions), and if you encounter problems with the Home Assistant Glow, you can indicate this in the [issues](https://github.com/klaasnicolaas/home-assistant-glow/issues).

./Klaas



## Related links

- [ESPHome 2024.6](https://esphome.io/changelog/2024.6.0.html)
- [Home Assistant 2024.7](https://www.home-assistant.io/blog/2024/07/03/release-20247/)
- [GitHub flow vs Git flow](https://www.split.io/blog/github-flow-vs-git-flow-whats-the-difference)

<!-- Links -->
[git_flow]: https://www.atlassian.com/git/tutorials/comparing-workflows/gitflow-workflow
[github_flow]: https://docs.github.com/en/get-started/using-github/github-flow
[http_request]: https://esphome.io/components/update/http_request
[packages]: https://esphome.io/guides/configuration-types#remote-git-packages
[build_workflow]: https://github.com/klaasnicolaas/home-assistant-glow/blob/develop/.github/workflows/build-firmware.yaml
[deploy_workflow]: https://github.com/klaasnicolaas/home-assistant-glow/blob/develop/.github/workflows/deploy-firmware.yaml

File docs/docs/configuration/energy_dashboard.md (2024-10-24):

---
id: energy_dashboard
title: Energy Dashboard
description: Learn how to set up an energy dashboard in Home Assistant to monitor your energy usage.
---

# Add to Energy Dashboard

To monitor your energy usage, you can add the Home Assistant Glow to the [Energy Dashboard][energy]. This dashboard provides an overview of your energy consumption, costs, and trends over time.

## Which entities to add?

You can choose between the following entities to add to the Energy Dashboard:

- **sensor.home_assistant_glow_daily_energy**
- **sensor.home_assistant_glow_total_energy**

It doesn't matter if the entity resets during the day for example due to an update/or hard reset after reboot. The long-term statistics in Home Assistant can handle that.

## Step-by-step guide to add entities

1. Open your Home Assistant dashboard/interface.
2. From the sidebar, click on **Energy**.
3. Click on the 3 dots in the top right corner and select **Energy Configuration**.
4. Click on **Add Consumption** and select the entity you want to add.
5. Optionally, you can setup the cost of your energy provider to get an overview of your energy costs.
6. Click **Save** to apply the changes.

:::note
If your Glow has just been added to Home Assistant, you may need to wait up to 2 hours before enough long-term statistics are stored to show in the Energy Dashboard.
:::

## Helpful resources

- [Home Assistant - Energy Management][energy]

[energy]: https://www.home-assistant.io/docs/energy

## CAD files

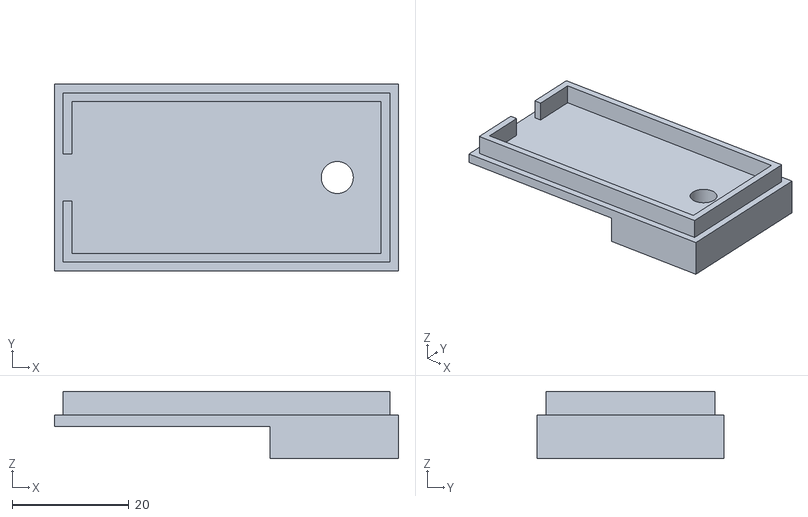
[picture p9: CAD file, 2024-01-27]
docs/static/cases/ESP32-WROOM-32D/ESP32-WROOM-32D_top_case.stl
59.0 x 32.0 x 11.5

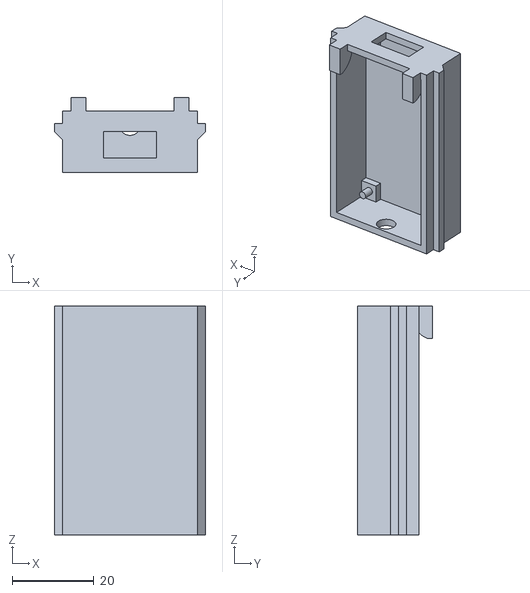
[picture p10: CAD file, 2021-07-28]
docs/static/cases/ESP32S/ESP32_bottom_side_v1.stl
37.0 x 18.3 x 56.0

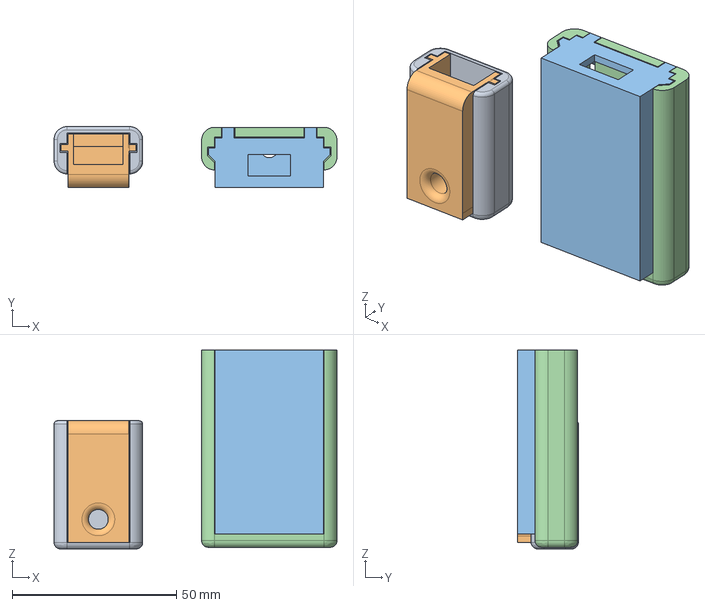
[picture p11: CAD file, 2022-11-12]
docs/static/cases/Home_Assistant_Glow.step
86.1 x 18.5 x 60.5 mm

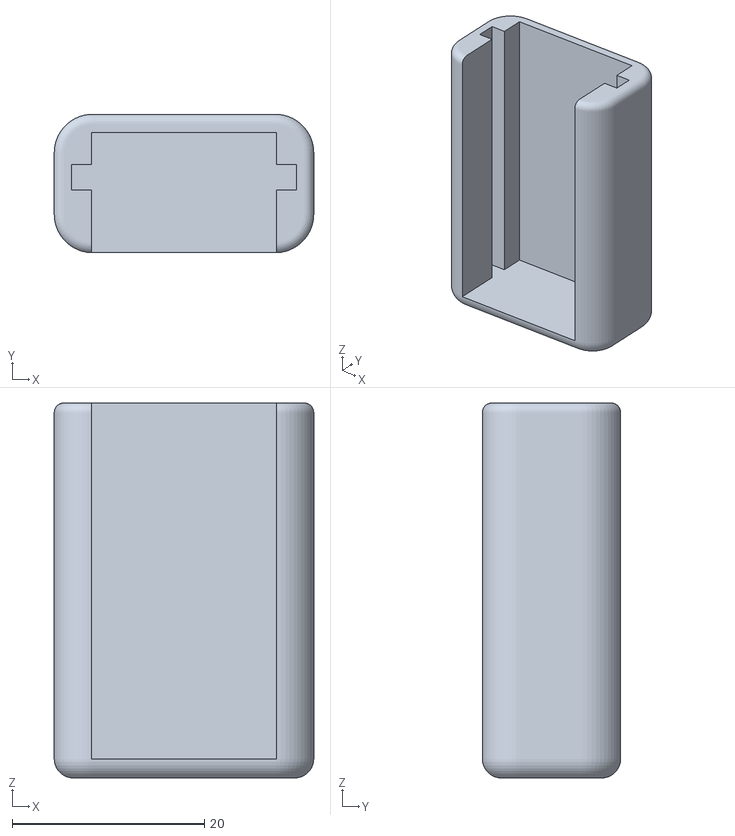
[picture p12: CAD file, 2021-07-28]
docs/static/cases/Photodiode_PCB/Sensor_top_side_v1.stl
27.0 x 14.4 x 39.0

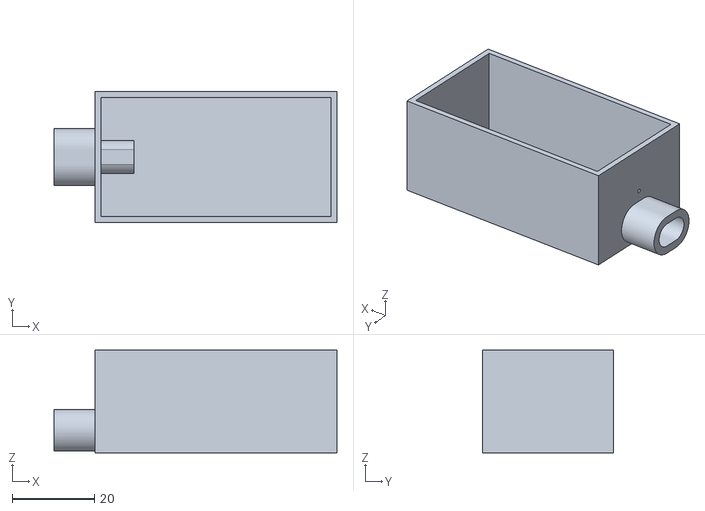
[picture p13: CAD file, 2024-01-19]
docs/static/cases/ESP32-WROOM-32D/ESP32-WROOM-32D_bottom_case.stl
69.0 x 32.0 x 25.0

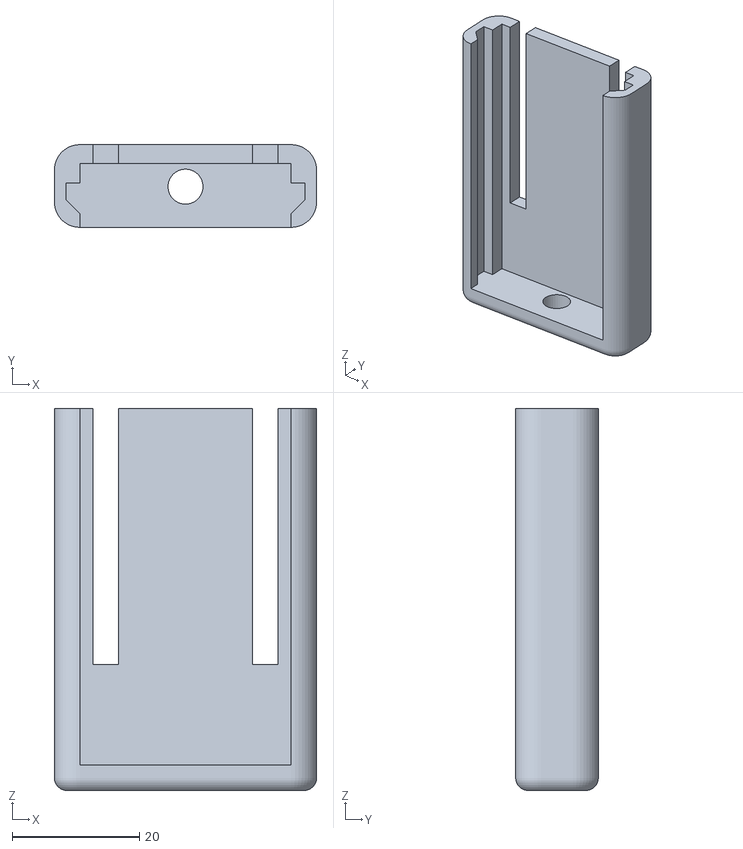
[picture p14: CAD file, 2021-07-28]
docs/static/cases/ESP32S/ESP32_top_side_v1.stl
41.2 x 13.0 x 60.0

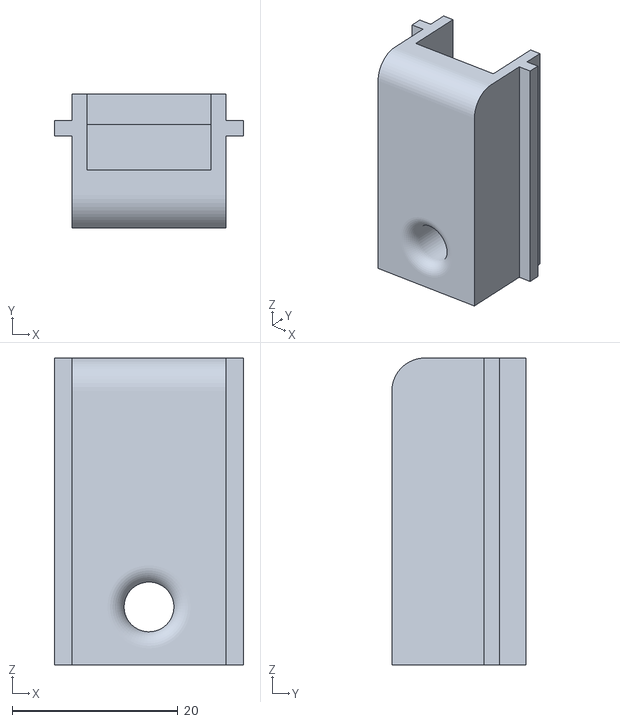
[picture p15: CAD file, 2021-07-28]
docs/static/cases/Photodiode_PCB/Sensor_bottom_side_v1.stl
22.8 x 16.2 x 37.0

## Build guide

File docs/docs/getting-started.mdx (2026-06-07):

---
id: getting-started
title: Getting Started
description: 'Instruction to get started with the Home Assistant Glow'
---

import Tabs from '@theme/Tabs';
import TabItem from '@theme/TabItem';
import FirmwareSelector from '@site/src/components/FirmwareSelector';
import { faUsb } from '@fortawesome/free-brands-svg-icons';

# Get started

This guide will walk you through the steps needed to set up your new Home Assistant Glow. You'll go through connecting the hardware, installing the necessary software, and configuring the settings to get everything up and running smoothly.

## <span style={{backgroundColor: 'var(--ifm-color-primary)', color: 'white', padding: '0.25rem 0.75rem', borderRadius: '999px', marginRight: '0.5rem', fontSize: '0.9em'}}>Step 1</span> Hardware

To get started, you need the right hardware first, fill your 🛒 or see if you already have the items in-house. Choose between an **ESP32** (recommended), **ESP32-C3**, or **ESP8266**.

| Nr. | Item | Where to buy |
|:----|:-----|:---|
|**1.**| ESP32 (recommended) | [AliExpress](https://s.click.aliexpress.com/e/_DdAe4Fl) \| [AliExpress][esp32-ali-shop] \| [Banggood][esp32-bg-shop] |
|**1.**| ESP32-C3 | [AliExpress](https://s.click.aliexpress.com/e/_c33qKQuJ) \| [AliExpress][esp32c3-ali-shop] |
|**1.**| ESP8266 | [AliExpress](https://s.click.aliexpress.com/e/_omR3PTr) \| [AliExpress][esp8266-ali-shop] \| [Banggood][esp8266-bg-shop] |
|**2.**| Dupont Jumpers (female to female) | [AliExpress](https://s.click.aliexpress.com/e/_DmbrJsj) \| [AliExpress][dupont-jumpers-ali-shop] \| [Banggood][dupont-jumpers-bg-shop] |
|**3.**| LM393 Photodiode | [AliExpress](https://s.click.aliexpress.com/e/_c3utxSRp) \| [AliExpress][photodiode-ali-shop] \| [Banggood][photodiode-bg-shop] |
|**4.**| LED RGB 5mm 4 pin - kathode | [AliExpress](https://s.click.aliexpress.com/e/_c3H3JVT9) \| [AliExpress][rgbled-ali-shop] \| [Banggood][rgbled-bg-shop] |

If you would like to prototype, I can also recommend the following items:

| Nr. | Item | Where to buy |
|:----|:-----|:---|
|**1.**| ESP32 Development Expansion Board (optional) | [AliExpress](https://s.click.aliexpress.com/e/_DdWH7ET) |

:::note
Keep in mind that besides the photodiode board there are also boards in circulation with an LDR. The expansion board is optional, but makes it easier to connect and prototype with the components.
:::

How everything should be connected can be found on the [wiring diagram](/docs/resources/schematics). Once this is done, you can proceed to step 2.

## <span style={{backgroundColor: 'var(--ifm-color-primary)', color: 'white', padding: '0.25rem 0.75rem', borderRadius: '999px', marginRight: '0.5rem', fontSize: '0.9em'}}>Step 2</span> Install firmware

Use the method below to provide your ESP with the correct firmware.

<Tabs>
  <TabItem value="usb" label={<><icon icon={faUsb} size="lg"/> USB</>}>

_Make sure this page is opened in a Chromium-based browser on a desktop. The software installation does not work with a tablet or phone._

1. Choose your firmware variant below (Standard or Basic) and click the blue **Connect** button to display a list of available USB devices.
2. To connect your ESP to your computer, follow these steps:
    - In the pop-up window, view the list of available USB devices.
    - Connect your ESP to your computer using a USB cable.
    - In the pop-up window, there should now appear a new entry. Select this USB serial port and select **Connect**.
3. Select **Install Home Assistant Glow**, then **Install**.
    - If the installation does not go well, you may need to first hold down the `boot` button and then click **Install**.
4. Once the installation is completed, click **Next**.
    - Add the Home Assistant Glow to your Wi-Fi network:
      - When prompted, select your network from the list and enter the credentials to your 2.4 GHz Wi-Fi network.
      - Click **Connect**.
      - The Home Assistant Glow is now connected to your network.
5. Congratulations 🎉 You have successfully installed the firmware on your Home Assistant Glow.

### Choose your firmware variant

<FirmwareSelector />

  </TabItem>
</Tabs>

## <span style={{backgroundColor: 'var(--ifm-color-primary)', color: 'white', padding: '0.25rem 0.75rem', borderRadius: '999px', marginRight: '0.5rem', fontSize: '0.9em'}}>Step 3</span> Connect to Home Assistant

There are two ways to connect the Glow to Home Assistant. You can do this during the firmware installation or via auto-discovery.

<Tabs>
  <TabItem value="during-install" label="During firmware installation" default>

1. Immediately after setting up your Wi-Fi network (from step 2), you will see a screen with the option **Add to Home Assistant**.
    - This opens the **My** link to Home Assistant (see image below).
      - If you have not used My Home Assistant before, you will need to configure it. If your Home Assistant URL is not accessible on `http://homeassistant.local:8123`, replace it with the URL to your Home Assistant instance.
2. Click on **Open the link**.
3. It opens your Home Assistant instance and asks you to set up, click **OK**.
4. Congratulations 🎉 You have successfully added the Home Assistant Glow to your Home Assistant instance.

<p align="left">
  My link to Home Assistant
</p>

  </TabItem>
  <TabItem value="auto-discovery" label="Auto-discovery">

When the Home Assistant Glow is added to a network to which your Home Assistant instance is also connected, your device will automatically be recognized in Home Assistant.

1. Under [**Settings** > **Devices & Services**](https://my.home-assistant.io/redirect/integrations/), your Home Assistant Glow should be discovered (see image below).
2. Click on **Configure**, at the discovered device.
3. It asks if you want to add the device and click **Submit**.
4. Congratulations 🎉 You have successfully added the Home Assistant Glow to your Home Assistant instance.

<p align="left">
  Auto-discovery in Home Assistant
</p>

  </TabItem>
</Tabs>

:::note
If you're prompted for an encryption key when adding the device, this means you may have accidentally adopted it in ESPHome Builder. The default firmware does not require an encryption key. See [FAQ: Encryption Key Required](/docs/faq/encryption_key_required) for more information.
:::

## <span style={{backgroundColor: 'var(--ifm-color-primary)', color: 'white', padding: '0.25rem 0.75rem', borderRadius: '999px', marginRight: '0.5rem', fontSize: '0.9em'}}>Step 4</span> Configure the Pulse Rate

To ensure that the Home Assistant Glow accurately measures energy consumption, you must set the correct pulse rate. The pulse rate refers to the number of pulses the energy meter sends per kilowatt-hour (kWh). Energy meters with a pulse LED will have an imp/kWh value indicated, such as 1000, 2000, etc.

By default, the Home Assistant Glow is configured to use a pulse rate of `1000`.

There are two ways to adjust the pulse rate:

<div style={{display: 'grid', gridTemplateColumns: '1fr 1fr', gap: '1.5rem', marginTop: '1rem'}}>

<div style={{border: '1px solid var(--ifm-color-emphasis-300)', borderRadius: '8px', padding: '1.5rem'}}>

### Option 1 - Via the web interface

Access the web interface by navigating to the IP address of your Home Assistant Glow. Once there, you'll find a table with a row labeled **Pulse rate**, where you can easily adjust the value in the column on the right.

<p align="left">
  Pulse rate in the web interface
</p>

</div>

<div style={{border: '1px solid var(--ifm-color-emphasis-300)', borderRadius: '8px', padding: '1.5rem'}}>

### Option 2 - In Home Assistant

1. Go to the device overview page of the Home Assistant Glow, via [**Settings** > **Devices & Services** > **ESPHome**](https://my.home-assistant.io/redirect/integration/?domain=esphome).
2. Adjust the value for the entity **Pulse rate**.

</div>

</div>

For problems with the measurements, see the [FAQ page](/docs/faq).

## <span style={{backgroundColor: 'var(--ifm-color-primary)', color: 'white', padding: '0.25rem 0.75rem', borderRadius: '999px', marginRight: '0.5rem', fontSize: '0.9em'}}>Step 5</span> Print the case

The final step is to wrap everything up in a casing that you can print. The files for this can be found on the [case resources page](/docs/resources/cases). If you do not have a 3D printer, there are platforms where you could place a print job or mount the Home Assistant Glow in a creative way 🙃

## <span style={{backgroundColor: 'var(--ifm-color-primary)', color: 'white', padding: '0.25rem 0.75rem', borderRadius: '999px', marginRight: '0.5rem', fontSize: '0.9em'}}>Step 6</span> Sit back and relax

Congratulations 🎉 You have gone successfully through everything to get started with the Home Assistant Glow 🌟 If you have any questions, please check the [FAQ page](/docs/faq) first and if you can't find the answer there, you can always ask your question on the [Github](https://github.com/klaasnicolaas/home-assistant-glow).

## Disclamer

Affiliate links are used on this website to support the Home Assistant Glow 🌟 project. Some Ad-blockers might block these links, and thus they seem to appear broken. You will have to temporarily disable ad-blocker to open these links.

{/* Hardware */}
[esp32-ali-shop]: https://tc.tradetracker.net/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
[esp32c3-ali-shop]: https://tc.tradetracker.net/?c=15640&m=12&a=417111&r=&u=%2Fitem%2F1005006391993583.html
[esp8266-ali-shop]: https://tc.tradetracker.net/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
[dupont-jumpers-ali-shop]: https://tc.tradetracker.net/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
[photodiode-ali-shop]: https://tc.tradetracker.net/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
[rgbled-ali-shop]: https://tc.tradetracker.net/?c=15640&m=12&a=417111&r=&u=%2Fitem%2F4000225253691.html

[esp32-bg-shop]: https://www.banggood.com/bang/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
[esp8266-bg-shop]: https://www.banggood.com/bang/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
[dupont-jumpers-bg-shop]: https://www.banggood.com/bang/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
[photodiode-bg-shop]: https://www.banggood.com/bang/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
[rgbled-bg-shop]: https://www.banggood.com/bang/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

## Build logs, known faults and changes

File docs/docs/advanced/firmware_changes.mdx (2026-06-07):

---
id: firmware_changes
title: Customizing the Firmware
description: Learn how to customize the firmware of the Glow using ESPHome.
---

# Customizing the Firmware

The Glow's firmware is built on [ESPHome](https://esphome.io), a platform designed for customization through simple YAML configurations. Whether you need to tweak the device's functionality or adapt it for different use cases, the process is straightforward.

This guide will walk you through how to adopt the device and customize its firmware using the [ESPHome Builder](https://esphome.io/guides/getting_started_hassio.html).

## Adopting the Device

Before making any changes to the firmware, you first need to adopt the device into the ESPHome. Once your ESPHome Builder is up and running, and the Glow is connected to your local network, you should see an option to **Take Control** of the device.

<p align="left">
  
</p>

:::warning Important: What happens when you adopt the device
Taking control of your Glow device will:
- Replace the default firmware with a custom ESPHome configuration
- Add an encryption key for secure API communication
- Configure the device to use Wi-Fi credentials from your ESPHome secrets
- **Stop automatic firmware updates** from [glow-energy.io](https://glow-energy.io)

After adoption, you will be responsible for managing firmware updates yourself through ESPHome Builder. You can always revert to the default firmware, but this will require re-installing the device.
:::

## Component Structure

The firmware is designed to be flexible for different ESP boards by breaking it into separate "components". Each main function of the device is kept in its own YAML file, making it easier to manage. The base configuration includes a few key components that handle the important functions of the device.

| Component | Description |
| :--- | :--- |
| [**basis.yaml**][component-basis] | Handles the basic, essential functionality of the device. |
| [**pulse_meter.yaml**][component-pulse_meter] | Manages pulse metering, useful for tracking energy usage. |
| [**status_led.yaml**][component-status_led] | Controls the status LED, allowing customization of its behavior or color based on the device's state. |
| [**updates.yaml**][component-updates] | Provides Over-the-Air ([OTA][ota]) update capabilities for easy firmware updates. |

### Making Your First Customization

Once your device is adopted, you can start customizing its behavior by editing the configuration files. In the ESPHome Builder, click on **EDIT** next to the device to open the YAML editor, where you can modify the configuration directly.

<p align="left">
  
</p>

The YAML configuration may seem short and incomplete because it relies on [remote packages][remote], which are loaded during the firmware build process. If you want to customize or modify anything, it's important to first find the used ESPHome component ID.

### Finding Component IDs

To customize a specific component, you need to know its ID. Here are the commonly used component IDs in Home Assistant Glow:

- **sensor_energy_pulse_meter** - The main energy pulse meter sensor
- **status_led** - The RGB status LED
- **ota_esphome** - OTA update component

You can find all component IDs by viewing the [component YAML files](https://github.com/klaasnicolaas/home-assistant-glow/tree/main/components) on GitHub.

### Example Customization

When you open the YAML editor, you'll see the default configuration for your Glow device. You can adjust this configuration or add new functionality by extending the existing components. For example, to change the behavior of the [pulse_meter], you can use the [!extend] feature to easily make the necessary changes.

Here's an example of increasing the accuracy of the total energy sensor to 5 decimal places:

```yaml title="your_glow_config.yaml"
sensor:
  - id: !extend sensor_total_energy
    accuracy_decimals: 5
```

:::note
Some settings, like the **internal filter**, are no longer configurable via YAML and must be adjusted through the Home Assistant UI or the built-in web interface. See the [Internal Filter](/docs/configuration/internal_filter) page for more information.
:::

## Reverting to Default Firmware

If you want to return to the default firmware and automatic updates from glow-energy.io, you can do so by re-installing the device:

1. Navigate to [glow-energy.io](https://glow-energy.io) and follow the USB installation method
2. This will overwrite your custom ESPHome configuration with the default firmware
3. You will lose any custom modifications you made
4. After re-installation, you will need to re-add the device to Home Assistant

:::tip
Before reverting, consider backing up your custom YAML configuration in case you want to use it again later.
:::

## Helpful Resources

- [ESPHome - Pulse Meter][pulse_meter]
- [ESPHome - Extend][!extend]
- [ESPHome - OTA Updates][ota]
- [ESPHome - Remote Packages][remote]

[pulse_meter]: https://esphome.io/components/sensor/pulse_meter.html
[!extend]: https://esphome.io/components/packages.html#extend
[ota]: https://esphome.io/components/ota/
[remote]: https://esphome.io/components/packages.html#remote-git-packages

[component-basis]: https://github.com/klaasnicolaas/home-assistant-glow/blob/main/components/basis.yaml
[component-pulse_meter]: https://github.com/klaasnicolaas/home-assistant-glow/blob/main/components/pulse_meter.yaml
[component-status_led]: https://github.com/klaasnicolaas/home-assistant-glow/blob/main/components/status_led.yaml
[component-updates]: https://github.com/klaasnicolaas/home-assistant-glow/blob/main/components/updates.yaml

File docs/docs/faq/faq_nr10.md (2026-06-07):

---
id: ghost_pulses
title: Unrealistic power spikes (ghost pulses)
description: What to do when you see unrealistic power spikes caused by ghost pulse detections
---

Linked issue: [#983][issue_983]

If you see sudden unrealistic power spikes (e.g. 1000 kW) in Home Assistant, this is likely caused by **ghost pulses**, which are false detections triggered by electrical noise or reflections near your meter's LED.

## What to do?

Increase the **Internal Filter** value on your device. This tells the pulse meter to ignore signals shorter than the configured duration, filtering out the noise that causes ghost detections.

You can adjust this in Home Assistant via the device configuration page, or via the built-in web interface. See the [Internal Filter](/docs/configuration/internal_filter) configuration page for step-by-step instructions.

A value between **1000 µs** (1 ms) and **10000 µs** (10 ms) is a good starting point for most setups.

## Related topics

- [Adjusting the Internal Filter](/docs/configuration/internal_filter)
- [Customizing the Firmware](/docs/advanced/firmware_changes)

[issue_983]: https://github.com/klaasnicolaas/home-assistant-glow/issues/983

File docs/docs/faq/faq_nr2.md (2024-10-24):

---
id: reduce_sensor_data
title: Reduce amount of sensor data
description: How to reduce the amount of sensor data
---

Depending on the configured **pulse rate**, the type of house/apartment and the heating system in use, the sensors that are exposed to Home Assistant may produce a lot of data. For example, with the default **pulse rate** of `1000`, a power consumption of 3600 W means that the sensors produce 2 HA state changes per second (which means 7200 state changes per hour).

If you don't need that kind of granularity, you can use [ESPHome sensor filters][filters] to reduce the rate of updates written to Home Assistant. This can be done by adding the following YAML code at the bottom of your Home Assistant Glow configuration file:

```yaml title="your_glow_config.yaml"
sensor:
  - id: !extend sensor_energy_pulse_meter
    filters:
      # Update the sensor with an average every 10th second. See
      - throttle_average: 10s
      - filter_out: NaN
    total:
      filters:
        # Update the sensor once per 0.1 kWh consumed, or every 5th minute, whichever happens sooner.
        - delta: 0.01
        - heartbeat: 300s
```

After applying the filters, only 396 state changes will be produced per hour. You can read more about making YAML adjustments on the [customizing the firmware](/docs/advanced/firmware_changes) page.

## Related topics

- [ESPHome sensor filters][filters]
- [ESPHome pulse meter](https://esphome.io/components/sensor/pulse_meter.html)
- [ESPHome total daily energy sensor](https://esphome.io/components/sensor/total_daily_energy.html)
- [Customizing the Firmware](/docs/advanced/firmware_changes)

[filters]: https://esphome.io/components/sensor/index.html#sensor-filters
[file]: https://github.com/klaasnicolaas/home-assistant-glow/blob/main/components/pulse_meter.yaml#L73

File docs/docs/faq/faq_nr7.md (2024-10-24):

---
id: abrupt_consumption_with_solar
title: Wrong reading when using solar
description: Sudden increase in consumption after a period of zero readings
---

Linked issue: [#274][issue_274]

If you have a solar system, and the consumption remains zero for some time and then gets a value from the sensor, you may see an abrupt increase in the total daily energy sensor value that doesn't match the actual consumption.

## What to do?

Try to use the `left` [calculation method][method] instead of the default (`right`). You can do this by editing your ESPHome device and add the following configuration at the bottom of your YAML file:

```yaml title="your_glow_config.yaml"
sensor:
  - id: !extend sensor_total_daily_energy
    method: left
```

## Related topics

- [ESPHome total daily energy sensor][method]
- [Customizing the Firmware](/docs/advanced/firmware_changes)

[method]: https://esphome.io/components/sensor/total_daily_energy.html
[issue_274]: https://github.com/klaasnicolaas/home-assistant-glow/issues/274

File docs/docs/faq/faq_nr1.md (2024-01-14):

---
id: wrong_soldered_diode
title: Wrong soldered diode
description: Know what a correct soldered diode looks like
---

Linked issue: [#34](https://github.com/klaasnicolaas/home-assistant-glow/issues/34)

A number of users have reported receiving the recommended diode board from various sources, only to find the diode has been soldered to the board the wrong way round. This can cause that your pulse LED is not measured regardless of the sensitivity you set for the diode.

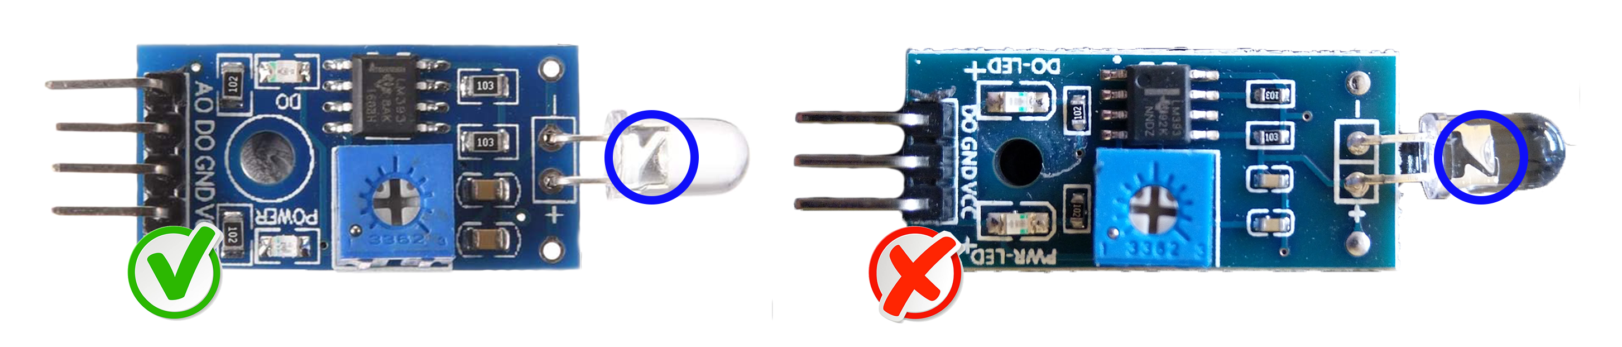
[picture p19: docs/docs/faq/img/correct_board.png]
Correct board


The large triangular part of the diode, should be soldered to the positive side of the board not the negative. If yours is orientated as above, you should desolder the photodiode invert it and resolder so the larger triangular part of the diode is connected to positive.

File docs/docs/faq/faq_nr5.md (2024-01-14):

---
id: failed_download_manifest
title: Failed to download manifest
description: Explanation of the manifest error and what you could do about it
---

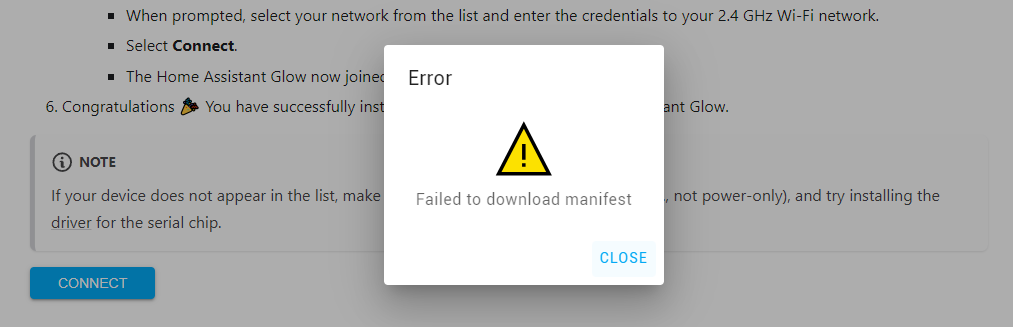
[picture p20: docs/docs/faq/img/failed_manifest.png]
Failed manifest


Linked issue: [#358][issue_358]

This error can occur if you try to install Home Assistant Glow on an ESP for which the correct firmware build is not available and is therefore missing from the manifest file. There are many variations in circulation, especially with the [ESP32][ESP32] and [ESP8266][ESP8266], and it is sometimes difficult to find out exactly which board a seller is selling (based on pictures).

## What to do?

If you encounter the above problem, please create an [issue](https://github.com/klaasnicolaas/home-assistant-glow/issues), include photos of your board and possibly a link to the shop where you bought it. This allows me to check if it's missing and consider adding a new firmware build to the repository.

### Advanced debugging

If you are an advanced user you could copy the complete yaml config to your own esphome environment, investigate exactly which board type you need and let me know.

[issue_358]: https://github.com/klaasnicolaas/home-assistant-glow/issues/358
[ESP32]: https://registry.platformio.org/platforms/platformio/espressif32/boards
[ESP8266]: https://registry.platformio.org/platforms/platformio/espressif8266/boards

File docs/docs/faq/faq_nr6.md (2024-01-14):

---
id: spinning_connecting
title: Connecting keeps spinning
description: What to do when the connecting keeps spinning during the installation process
---

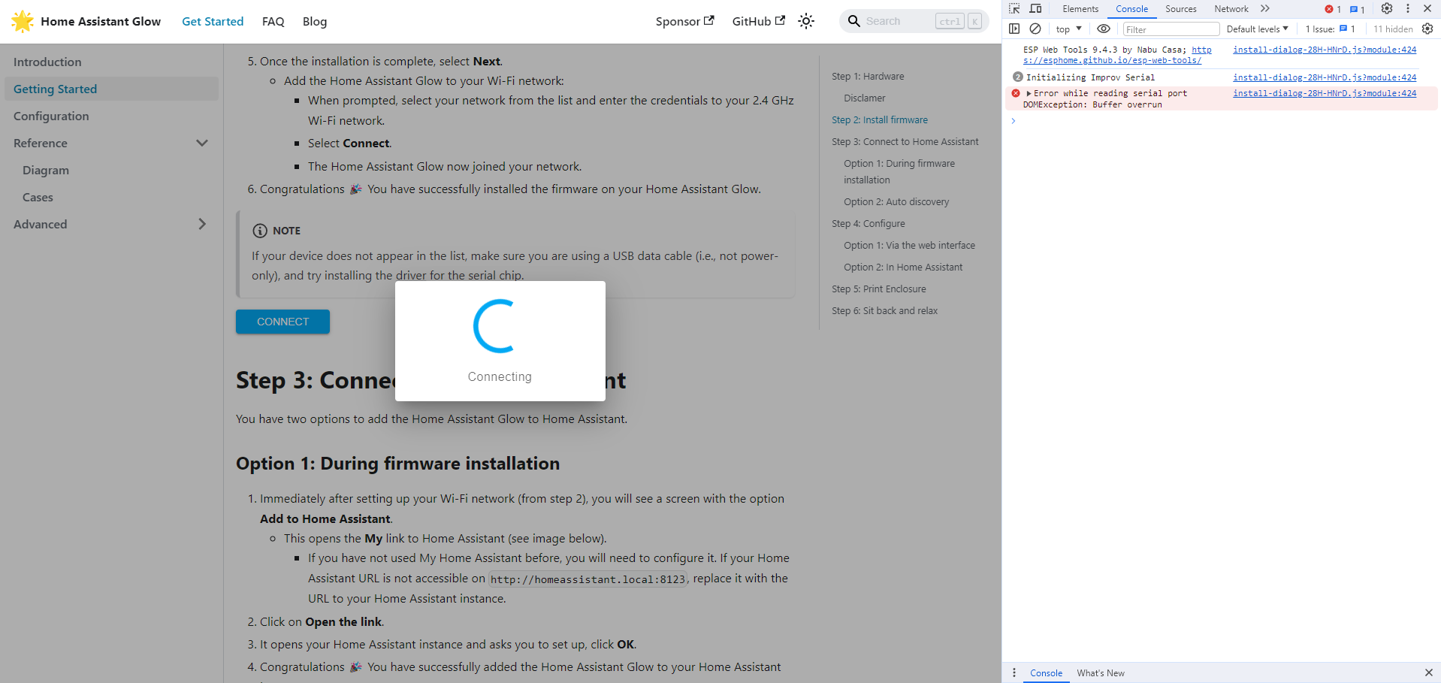
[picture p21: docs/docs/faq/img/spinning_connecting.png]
Spinning connecting


This error can occur during the installation process and is usually caused by a bad connection between the ESP and the computer. This can be caused by a bad USB cable, a bad USB port or a bad connection on the ESP itself. If you open developer tools in your browser (F12) and go to the console tab, you may see the following error:

```text
Error while reading serial port DOMException: Buffer overrun
```

## What to do?

Reconnect the cable to the ESP and try the installation process again, you could also try a different cable.

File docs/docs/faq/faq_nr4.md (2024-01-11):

---
id: out_of_memory
title: Out of memory (error 4)
description: What to do when you get an error 4 / out of memory error
---

Linked issue: [#240][issue_240]

With this error there is a chance that the instance your ESPHome is running on may be out of memory (possibly on a Raspberry Pi with less RAM), you can solve this by limiting the number of processes at compiling time using [compile_process_limit][compile_process_limit].

```yaml title="home-assistant-glow/esp32.yaml"
esphome:
  compile_process_limit: 1
```

[issue_240]: https://github.com/klaasnicolaas/home-assistant-glow/issues/240
[compile_process_limit]: https://esphome.io/components/esphome.html?highlight=compile_process_limit

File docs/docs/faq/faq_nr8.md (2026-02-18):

---
id: how_to_set_ota_password
title: How to set OTA password
description: How to set an OTA password for your ESPHome device
---

Since [release v4.1.0](/blog/release-4.1.0#esphome-ota-updates), the OTA component is in a separate (external) [package], so it is no longer in your config when you adopt the Home Assistant Glow in ESPHome Builder (app). Fortunately, the ESPHome platform has an ID under the OTA component so you can use [!extend]. This way, you can set the OTA password in your Glow configuration.

```yaml title="your_glow_config.yaml"
ota:
  - id: !extend ota_esphome
    password: "your_password"
```

In the example above, replace `your_password` with the password you want to use for OTA updates. Of course, this way you can not only add a password, but also override all platform options with your own settings.

## Related topics

- [ESPHome - OTA updates][esphome_ota]
- [ESPHome - Extend][!extend]
- [Customizing the Firmware](/docs/advanced/firmware_changes)

[esphome_ota]: https://esphome.io/components/ota.html
[!extend]: https://esphome.io/components/packages.html#extend
[package]: https://esphome.io/components/packages.html#remote-git-packages

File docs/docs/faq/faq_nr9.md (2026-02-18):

---
id: encryption_key_required
title: Home Assistant asks for encryption key
description: Why Home Assistant asks for an encryption key when adding the Glow device
---

Linked issue: [#870][issue_870]

When adding your Glow to Home Assistant, you may be prompted to enter an encryption key. This should not happen if you're using the default firmware installed via this website.

## What causes this?

The default firmware available on this [website][website] does not include an encryption key in the YAML configuration. However, if you have made any modifications to the firmware, an encryption key may have been added automatically.

The most common scenario is:

1. You added the Glow to the ESPHome Builder (app)
2. You clicked "Take Control" in ESPHome Builder
3. ESPHome automatically installed custom firmware and added an `encryption` -> `key:` entry to your YAML configuration

## What to do?

If you're using custom firmware through ESPHome Builder, you need to find the encryption key in your device's YAML configuration:

1. Open ESPHome Builder
2. Find your Glow device (e.g., *"home-assistant-glow-XXXX"*)
3. Click **Edit** to view the YAML configuration
4. Look for the `api:` section with the `encryption` -> `key:` entry
5. Use this key when adding the device to Home Assistant

:::note
Once you start using the ESPHome Builder and make custom firmware modifications, you are responsible for managing your own configuration, including the encryption key. Using ESPHome Builder requires advanced skills and understanding of how ESPHome works.
:::

## Avoiding this issue

If you want to avoid encryption key issues:

- **Stick with the default firmware** if you don't need customization - this way you get automatic updates and no encryption complexity
- **Only adopt the device in ESPHome Builder** if you need specific customizations that aren't available in the default firmware

See [Customizing the Firmware](/docs/advanced/firmware_changes) for more information about when and why you might want to customize.

## Related topics

- [ESPHome - Native API][esphome_api]
- [Customizing the Firmware](/docs/advanced/firmware_changes)

[esphome_api]: https://esphome.io/components/api.html
[issue_870]: https://github.com/klaasnicolaas/home-assistant-glow/issues/870
[website]: https://glow-energy.io

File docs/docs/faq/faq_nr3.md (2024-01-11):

---
id: daily_energy_reset
title: Daily energy won't reset
description: What to do when the daily energy entity won't reset
---

Linked issue: [#140][issue_140]

By default, the Home Assistant Glow uses the `homeassistant` [time platform][time-platform], which synchronizes the current time via the native API from your home assistant config. If this doesn't work, you could consider using the `sntp` time platform, as in the example below:

```yaml title="components/basis.yaml"
time:
  - platform: sntp
    id: sntp_time
```

[issue_140]: https://github.com/klaasnicolaas/home-assistant-glow/issues/140
[time-platform]: https://esphome.io/components/time.html#home-assistant-time-source

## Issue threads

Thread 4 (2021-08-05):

Cant see any entity or values

Snobs76, 2021-08-05:
I`ve got  a working pulse counter and in the past I send the values via mqtt.
Now I copyed your yaml file and do the changes for my secrets etc. At the webinterface i can see all the values and their updates. But I`ve got no entity at ha nothing at developer console, What I`m doing wrong i want to use the new energy function.

Please help.
Best regards
Sascha

```
---
#
substitutions:
  device_name: pulse_counter
  friendly_name: House
  device_description: "Measure your energy consumption with the pulse LED on your smart meter"
  pulse_pin: GPIO0
  status_led: GPIO2

esphome:
  name: '${device_name}'
  comment: '${device_description}'
  project:
    name: "klaasnicolaas.home_assistant_glow"
    version: "1.1.1"
  platform: ESP8266
  board: d1_mini

wifi:
  ssid: !secret wifi_ssid
  password: !secret wifi_pass

  # Enable fallback hotspot (captive portal) in case wifi connection fails
  ap:
    ssid: '${device_name}'
    password: !secret fallback_password

captive_portal:

# Enable logging
logger:

# Enable Home Assistant API
api:
  #password: !secret esphome_api_password

ota:
  safe_mode: true
  reboot_timeout: 10min
  num_attempts: 5

web_server:
  port: 80
  auth:
    username: !secret esphome_web_username
    password: !secret esphome_web_password

output:
  # - platform: gpio
  #   pin: GPIO5
  #   id: output_blue
  - platform: gpio
    pin: GPIO2
    id: output_red
  - platform: gpio
    pin: GPIO5
    id: output_green

light:
  - platform: binary
    internal: true
    id: led_red
    name: Red
    output: output_red

# Status LED for connection
status_led:
  pin:
    # Blue LED
    number: ${status_led}

# Sensors for ESP version and WIFI information
text_sensor:
  - platform: version
    hide_timestamp: true
    name: "${friendly_name} - ESPHome Version"
  - platform: wifi_info
    ip_address:
      name: "${friendly_name} - IP Address"
      icon: mdi:wifi
    ssid:
      name: "${friendly_name} - Connected SSID"
      icon: mdi:wifi-strength-2

sensor:
  - platform: pulse_meter
    name: '${friendly_name} - Power consumption'
    unit_of_measurement: 'Watt'
    icon: mdi:flash-outline
    accuracy_decimals: 0
    pin: ${pulse_pin}
    on_value:
      then:
        - light.turn_on:
            id: led_red
            flash_length: 400ms
    filters:
      # multiply value = (60 / imp value) * 1000
      - multiply: 12
    total:
      name: '${friendly_name} - Total energy'
      unit_of_measurement: 'kWh'
      icon: mdi:circle-slice-3
      last_reset_type: auto
      state_class: measurement
      device_class: energy
      accuracy_decimals: 3
      filters:
        - multiply: 0.001
```

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

klaasnicolaas, 2021-08-05:
If all is well, Home Assistant will automatically recognize a new device and ask if you want to add it.

Snobs76, 2021-08-05:
Thank you for your replay. Thats the problem, HA did not recognize a new device, I delete the old ESP Device and restartet my HA Host not only software. No new device. Any ideas ?

Snobs76, 2021-08-05:
I figured out, he won't find the devices automatically for some reason. I have now set it up manually and watch out, everything I need is there. Thanks for the yaml and your support.

Closed 2021-08-05.

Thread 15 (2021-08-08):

Leaps in readings

PhantoMMM, 2021-08-08:
Good afternoon! Sometimes the power consumption sensor transmits very high values (more than 150000 watts), and then shows the correct data again. This happens several times a minute. It can be fixed?

PhantoMMM, 2021-08-08:
https://postimg.cc/gallery/sjyxt4q

KShips, 2021-08-08:
I had this problem, it was due to too much light from outside getting to the sensor. 2 options are to either block out more of the sensor or turn the trimpot sensitivity down, combination of both and bit of testing seems to have got mine working well.

PhantoMMM, 2021-08-08:
I set the sensitivity to the minimum level. Maybe you can apply some kind of software filter? My electricity meter has 6400 flashes per kilowatt, if that's important. I am using Esp8266 module.

klaasnicolaas, 2021-08-08:
It sounds like the sensor is measuring ghost flashes, which happens when the time between 2 pulses is very short. Could you share how your sensor is mounted on your meter? And have you adjusted your multiply values needed for your 6400 imp/kWh rate?

PhantoMMM, 2021-08-08:
My config looks like this:
---
#
substitutions:
  device_name: home_assistant_glow
  friendly_name: House
  device_description: "Measure your energy consumption with the pulse LED on your smart meter"
  pulse_pin: GPIO12
  status_led: GPIO5

esphome:
  name: '${device_name}'
  comment: '${device_description}'
  project:
    name: "klaasnicolaas.home_assistant_glow"
    version: "1.1.2"
  platform: esp8266
  board: nodemcu

wifi:
  ssid: Vladofon
  password: VlAdIsLaV091078

  # Enable fallback hotspot (captive portal) in case wifi connection fails
  ap:
    ssid: '${device_name}'
    password: esphome291

captive_portal:

# Enable logging
logger:

# Enable Home Assistant API
api:
  password: 091078091078

ota:
  safe_mode: true
  reboot_timeout: 10min
  num_attempts: 5

web_server:
  port: 80
  auth:
    username: admin
    password: 091078

output:
  # - platform: gpio
  #   pin: GPIO5
  #   id: output_blue
  - platform: gpio
    pin: GPIO2
    id: output_red
  - platform: gpio
    pin: GPIO4
    id: output_green

light:
  - platform: binary
    internal: true
    id: led_red
    name: Red
    output: output_red

# Status LED for connection
status_led:
  pin:
    # Blue LED
    number: ${status_led}

# Sensors for ESP version and WIFI information
text_sensor:
  - platform: version
    hide_timestamp: true
    name: "${friendly_name} - ESPHome Version"
  - platform: wifi_info
    ip_address:
      name: "${friendly_name} - IP Address"
      icon: mdi:wifi
    ssid:
      name: "${friendly_name} - Connected SSID"
      icon: mdi:wifi-strength-2

sensor:
  - platform: pulse_meter
    name: '${friendly_name} - Power consumption'
    unit_of_measurement: 'W'
    state_class: measurement
    device_class: power
    icon: mdi:flash-outline
    accuracy_decimals: 0
    pin: ${pulse_pin}
    on_value:
      then:
        - light.turn_on:
            id: led_red
            flash_length: 400ms
    filters:
      # multiply value = (60 / imp value) * 1000
      - multiply: 9.375
    total:
      name: '${friendly_name} - Total energy'
      unit_of_measurement: 'kWh'
      icon: mdi:circle-slice-3
      last_reset_type: auto
      state_class: measurement
      device_class: energy
      accuracy_decimals: 3
      filters:
        # multiply value = 1 / imp value
        - multiply: 0.00015625

The sensor was previously used with Mysensor and showed correct values.

ArkhonTiger, 2021-08-10:
I'm also getting this. Seems to occur with any level of usage, not just high usage. Log shows a single spike of 360000.00000W each time and then drops back to normal on the next read. (and it's always 360000)

`[10:51:00][V][sensor:035]: 'House - Total energy': Received new state 366.000000
[10:51:00][VV][sensor.filter:013]: Filter(0x3ffb9444)::input(366.000000)
[10:51:00][VV][sensor.filter:020]: Filter(0x3ffb9444)::output(0.366000) -> SENSOR
[10:51:00][D][sensor:127]: 'House - Total energy': Sending state 0.36600 kWh with 3 decimals of accuracy
[10:51:00][VV][api.service:105]: send_sensor_state_response: SensorStateResponse {
  key: 2690257735
  state: 0.366
  missing_state: NO
}

[10:51:00][V][sensor:035]: 'House - Power consumption': Received new state 6000.000000
[10:51:00][VV][sensor.filter:013]: Filter(0x3ffb928c)::input(6000.000000)
[10:51:00][VV][sensor.filter:020]: Filter(0x3ffb928c)::output(360000.000000) -> SENSOR
[10:51:00][D][sensor:127]: 'House - Power consumption': Sending state 360000.00000 W with 0 decimals of accuracy
[10:51:00][D][light:093]: 'Red' Setting:
[10:51:00][D][light:125]:   Flash Length: 0.4s
[10:51:00][VV][api.service:105]: send_sensor_state_response: SensorStateResponse {
  key: 2274151077
  state: 360000
  missing_state: NO
}

[10:51:07][V][sensor:035]: 'House - Power consumption': Received new state 8.277003
[10:51:07][VV][sensor.filter:013]: Filter(0x3ffb928c)::input(8.277003)
[10:51:07][VV][sensor.filter:020]: Filter(0x3ffb928c)::output(496.620209) -> SENSOR
[10:51:07][D][sensor:127]: 'House - Power consumption': Sending state 496.62021 W with 0 decimals of accuracy
[10:51:07][D][light:093]: 'Red' Setting:
[10:51:07][D][light:102]:   State: ON
[10:51:07][D][light:125]:   Flash Length: 0.4s
[10:51:07][VV][api.service:105]: send_sensor_state_response: SensorStateResponse {
  key: 2274151077
  state: 496.62
  missing_state: NO
}
[10:51:07][V][sensor:035]: 'House - Total energy': Received new state 367.000000
[10:51:07][VV][sensor.filter:013]: Filter(0x3ffb9444)::input(367.000000)
[10:51:07][VV][sensor.filter:020]: Filter(0x3ffb9444)::output(0.367000) -> SENSOR
[10:51:07][D][sensor:127]: 'House - Total energy': Sending state 0.36700 kWh with 3 decimals of accuracy
[10:51:07][VV][api.service:105]: send_sensor_state_response: SensorStateResponse {
  key: 2690257735
  state: 0.367
  missing_state: NO`

Fossdal, 2021-08-11:
I have the same issue.
i have a 357lf sensor. and it is gaffa taped to the meter, and the meter is inside a closet. so no external light.
i have tried to test it outside. when i cover the sensor it gives a reading. and when i uncover it again it gives a reading again. so it almost looks like it is giving a reading on both edges (up and down)

WizBangCrash, 2021-08-16:
I have the same issue too. I and using an esp8266 too. I have tried adjusting the light sensor sensitivity etc. and my meter is in a dark cupboard, so no additional light to confuse the sensor.
Could this be esp8266 related, as the original suggests using an esp32?

WizBangCrash, 2021-08-16:
I think I may have root caused this one.
I read about the `internal_filter` option for the pulse meter sensor on esphome.io and added the following line to my configuration file:
```
    internal_filter: 50ms
```
Since adding this line I have had no false readings for the last hour and they used to occur every few seconds.
The default value for `internal_filter` Is 15us, so I suspect the meter LED is registering as multiple flashes since it is probably driven from a PWM :-)

Fossdal, 2021-08-16:
I have tried with the internal_filter with different values, but no different behavior. i also tried with at pull down resistor.
when i tried with a 100nF capacitor it worked. so it has to be some kind of noise

PhantoMMM, 2021-08-19:
I also solved my problem using a capacitor.

klaasnicolaas, 2021-08-19:
In that case, I think we can close this issue?

PhantoMMM, 2021-08-19:
Yes, I think you can close it. Thanks !

moorep999, 2021-09-18:
Since I’m new to electronics, would someone please ELI5 where this 100nf capacitor sits. I’m having a nightmare getting accurate readings.

Closed 2021-08-19.

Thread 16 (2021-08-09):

Extra Config for LDRs

maverikgrass, 2021-08-09:
I know that using an LDR isn't recommended, but for some reason finding a 4 pin photodiode or similar is impossible down here in Australia. The only way I can get one is from Alibaba or similar and I don't want to wait that long. Can anyone share with me the extra config and different wiring guide for using an LDR thanks!

jesserockz, 2021-08-09:
You can attempt to use an LDR in the same way as a photodiode. But you may have issues with the voltage not getting high enough to trigger the pulse_meter to get a reading or false readings. You will need to experiment with it.

jesserockz, 2021-08-09:
Also see #10

maverikgrass, 2021-08-09:
Thanks, I'm a little bit of a noob when it comes to electronics, is there anything else I need to add, a resistor or something? And is there a specific GPIO pin that would be best to get used. Also this is first time using ESPHome or anything or the sort, is there any code I have to edit/add?
Side note I'm using an esp8266 instead. I got the webgui and everything working, I just can't figure out the photoresistor.

TomW1605, 2021-08-09:
would a photo transistor like this one work better than an LDR?
https://core-electronics.com.au/photo-transistor-light-sensor.html (aussie site)

maverikgrass, 2021-08-09:
Honestly I have no clue, like I said, I'm an electronics noob. This is essentially my starter project.

maverikgrass, 2021-08-09:
I need some help here, I'm stuck. I've got all the pins hooked up. but It just doesn't do anything.

ArkhonTiger, 2021-08-09:
Ahoy!  I am Australian too and also had issues getting the right photodiode. I tried a few from Jaycar but they were all tuned for Infrared and wouldn't pick up the tiny light on my meter.

I also had no luck with _any_ LDR. In the end, I got a working solution with this:

Get this 4-wire board from Jaycar:
https://www.jaycar.com.au/arduino-compatible-microphone-sound-sensor-module/p/XC4438

Remove the microphone and in its place solder on a photodiode from this thing:
https://www.jaycar.com.au/photo-interrupter/p/ZD1901  (you'll need to break it open to get at them.

 Its a hacky job but its working perfectly now.

maverikgrass, 2021-08-09:
Thanks! I've ordered those two bits for pick up tomorrow and I'll give It a shot. Any tips on hacking apart the photo interrupter?

benbeton, 2021-08-09:
will it work with this one: would be a nice an cheap solution, haven't found the listed part in germany
https://www.amazon.de/gp/product/B00EFOTJZE/ref=ppx_yo_dt_b_asin_title_o00_s00?ie=UTF8&psc=1

ArkhonTiger, 2021-08-09:
> Thanks! I've ordered those two bits for pick up tomorrow and I'll give It a shot. Any tips on hacking apart the photo interrupter?

I just used pliers and side cutters. It's not a particularly solid thing, just take it slow so you don't mangle the legs.

You'll eventually see a small tab thats holding them in place. Pry/cut the tab and you'll be good to slide it out.

jesserockz, 2021-08-09:
> Get this 4-wire board from Jaycar:
> https://www.jaycar.com.au/arduino-compatible-microphone-sound-sensor-module/p/XC4438

Yeah these boards underneath are very common for converting analog to digital with a user changeable threshold.

maverikgrass, 2021-08-09:
Just a side note, I've completely isolated the issue to being the Photoresistor, I simply tested by shorting the to leads of the LDR and it registered as a pulse so its not a code issue, Phew! I'll update you all tomorrow once I test the new sensors.

maverikgrass, 2021-08-10:
Is there a specific direction I have to wire the component I ripped out? The longer leg to the right or?

maverikgrass, 2021-08-10:
Well I concede I do not have the skills nor the patience to try and solder this tiny piece to the board, I've completely burned up the pads on the board, and now I'm just going to have to wait 8 months for the original board to get here from china.

walkerleigh, 2021-08-10:
I was going to say that the emitter should be connected to the trace which runs down to the 'G' terminal

maverikgrass, 2021-08-10:
Oh, thanks for your help anyway. To be honest I kinda lost my cool there. Not to worry though, I got a regular old LDR working. I know they're worse, for quite a few reasons, but this isnt mission critical for me so it'll do.

Closed 2021-08-10.

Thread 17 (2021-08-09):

Every other power consumption reading is 0W.

bgmn, 2021-08-09:
Every other power consumption reading is 0 W. I can see that the photodiode works correctly from its led and it flashes just like the led on the power meter. I have a meter that has 10000 impulses per 1 kWh.

I have shortened the config because i have no need for the leds or web server.

```
#
substitutions:
  device_name: home_assistant_glow
  friendly_name: House
  device_description: "Measure your energy consumption with the pulse LED on your smart meter"
  pulse_pin: GPIO12

esphome:
  name: '${device_name}'
  comment: '${device_description}'
  project:
    name: "klaasnicolaas.home_assistant_glow"
    version: "1.1.2"
  platform: ESP32
  board: esp32doit-devkit-v1

wifi:
  ssid: "redblock"
  password: "si(ni2neb3fanhGEe!vo4neGna"
  fast_connect: true

  # Enable fallback hotspot (captive portal) in case wifi connection fails
  ap:
    ssid: '${device_name}'
    password: "luVL44uRRwpW"

captive_portal:

# Enable logging
logger:

# Enable Home Assistant API
api:
  password: "asidna3tq3t9ah2A)RF#HA9ah3fa"

ota:
  safe_mode: true
  reboot_timeout: 10min
  num_attempts: 5

sensor:
  - platform: pulse_meter
    internal_filter: 8us
    name: '${friendly_name} - Power consumption'
    unit_of_measurement: 'W'
    state_class: measurement
    device_class: power
    icon: mdi:flash-outline
    accuracy_decimals: 0
    pin: ${pulse_pin}
    filters:
      # multiply value = (60 / imp value) * 1000
      - multiply: 6
    total:
      name: '${friendly_name} - Total energy'
      unit_of_measurement: 'kWh'
      icon: mdi:circle-slice-3
      last_reset_type: auto
      state_class: measurement
      device_class: energy
      accuracy_decimals: 3
      filters:
        # multiply value = 1 / imp value
        - multiply: 0.0001`
```

klaasnicolaas, 2021-08-09:
I think you have to play with the `internal_filter` a bit, because you get 10x as many pulses for 1 kWh there is a good chance that it doesn't count because it is so many times in a row 🤔

bgmn, 2021-08-09:
I have tried it with 4 and 8 us, but it doesn't change anything. My consumption is under 1000 Watts so the led isn't blinking too fast.

Here is a portion of my log
```
17:26:47][D][sensor:127]: 'House - Power consumption': Sending state 960.00000 W with 0 decimals of accuracy
[17:26:47][D][sensor:127]: 'House - Total energy': Sending state 5.67330 kWh with 3 decimals of accuracy
[17:26:47][D][sensor:127]: 'House - Power consumption': Sending state 0.00000 W with 0 decimals of accuracy
[17:26:47][D][sensor:127]: 'House - Total energy': Sending state 5.67470 kWh with 3 decimals of accuracy
[17:26:47][D][sensor:127]: 'House - Power consumption': Sending state 962.56689 W with 0 decimals of accuracy
[17:26:47][D][sensor:127]: 'House - Total energy': Sending state 5.67480 kWh with 3 decimals of accuracy
[17:26:47][D][sensor:127]: 'House - Power consumption': Sending state 0.00000 W with 0 decimals of accuracy
[17:26:47][D][sensor:127]: 'House - Total energy': Sending state 5.67580 kWh with 3 decimals of accuracy
[17:26:47][D][sensor:127]: 'House - Power consumption': Sending state 962.56689 W with 0 decimals of accuracy
[17:26:47][D][sensor:127]: 'House - Total energy': Sending state 5.67710 kWh with 3 decimals of accuracy
[17:26:48][D][sensor:127]: 'House - Power consumption': Sending state 0.00000 W with 0 decimals of accuracy
[17:26:48][D][sensor:127]: 'House - Power consumption': Sending state 952.38098 W with 0 decimals of accuracy
[17:26:48][D][sensor:127]: 'House - Total energy': Sending state 5.67730 kWh with 3 decimals of accuracy
[17:26:48][D][sensor:127]: 'House - Power consumption': Sending state 0.00000 W with 0 decimals of accuracy
[17:26:48][D][sensor:127]: 'House - Total energy': Sending state 5.67830 kWh with 3 decimals of accuracy
[17:26:48][D][sensor:127]: 'House - Total energy': Sending state 5.67850 kWh with 3 decimals of accuracy
[17:26:48][D][sensor:127]: 'House - Total energy': Sending state 5.67990 kWh with 3 decimals of accuracy
[17:26:49][D][sensor:127]: 'House - Power consumption': Sending state 962.56689 W with 0 decimals of accuracy
[17:26:49][D][sensor:127]: 'House - Total energy': Sending state 5.68080 kWh with 3 decimals of accuracy
[17:26:49][D][sensor:127]: 'House - Power consumption': Sending state 0.00000 W with 0 decimals of accuracy
[17:26:49][D][sensor:127]: 'House - Power consumption': Sending state 954.90723 W with 0 decimals of accuracy
[17:26:49][D][sensor:127]: 'House - Total energy': Sending state 5.68090 kWh with 3 decimals of accuracy
[17:26:49][D][sensor:127]: 'House - Power consumption': Sending state 0.00000 W with 0 decimals of accuracy
[17:26:49][D][sensor:127]: 'House - Total energy': Sending state 5.68200 kWh with 3 decimals of accuracy
[17:26:49][D][sensor:127]: 'House - Power consumption': Sending state 960.00000 W with 0 decimals of accuracy
[17:26:49][D][sensor:127]: 'House - Total energy': Sending state 5.68250 kWh with 3 decimals of accuracy
[17:26:49][D][sensor:127]: 'House - Power consumption': Sending state 0.00000 W with 0 decimals of accuracy
[17:26:49][D][sensor:127]: 'House - Total energy': Sending state 5.68330 kWh with 3 decimals of accuracy
[17:26:50][D][sensor:127]: 'House - Total energy': Sending state 5.68440 kWh with 3 decimals of accuracy
[17:26:51][D][sensor:127]: 'House - Total energy': Sending state 5.68480 kWh with 3 decimals of accuracy
[17:26:51][D][sensor:127]: 'House - Total energy': Sending state 5.68590 kWh with 3 decimals of accuracy
[17:26:51][D][sensor:127]: 'House - Power consumption': Sending state 960.00000 W with 0 decimals of accuracy
[17:26:51][D][sensor:127]: 'House - Total energy': Sending state 5.68600 kWh with 3 decimals of accuracy
```

bgmn, 2021-08-09:
I think that this is not the case. If I calculated correctly my meter will flash 20 000 times per hour, if I'm using 20 kWh. That means 55,56 pulses per second. So 1 second equals 1 000 000 microseconds. One pulse will have time to rise and fall for 18 000 microseconds.

I tried also with pulse_counter but it calculates usage and consumption in certain time period. Pulse meter calculates it every time when there is a pulse. As you can see from my logs the total energy rises every time it is seen on the logs but for some reason consumption is always every second time zero.

The timeout for zero pulses per minute is 5 minutes so this can't be the case.

Is anyone else able to reproduce this error? How can I debug this

bgmn, 2021-08-09:
Still thinking about this. I looked at the logs and there are sometimes huge consumption numbers

It baffles me that the total energy seems to accumulate correctly even though consumption is zero or 360 000 W. Could there be some kind of error with the pulse_meter library or do I have defective esp32?

```
[23:02:34][D][sensor:127]: 'House - Power consumption': Sending state 853.08057 W with 0 decimals of accuracy
[23:02:34][D][sensor:127]: 'House - Total energy': Sending state 0.07910 kWh with 3 decimals of accuracy
[23:02:34][D][sensor:127]: 'House - Power consumption': Sending state 360000.00000 W with 0 decimals of accuracy
[23:02:34][D][sensor:127]: 'House - Total energy': Sending state 0.07920 kWh with 3 decimals of accuracy
[23:02:35][D][sensor:127]: 'House - Power consumption': Sending state 0.00000 W with 0 decimals of accuracy
[23:02:35][D][sensor:127]: 'House - Total energy': Sending state 0.07980 kWh with 3 decimals of accuracy
```

LarsNorgaard, 2021-08-10:
I think you have to use ms instead of μs. They say for power-meter it could be 50-100ms.

bgmn, 2021-08-10:
> I think you have to use ms instead of μs. They say for power-meter it could be 50-100ms.

Yes! That was it. All the documentation talks about μs and I of course thought that I have to use them too. Now I have 5ms as an internal_filter value and it works.

Thank you for you help!

Closed 2021-08-10.

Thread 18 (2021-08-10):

Active/Reactive power measurements

phrfpeixoto, 2021-08-10:
Hi,

I'm not sure this is the right place for this question, so if it's not, please feel free to close this issue/point me elsewhere.

TL-DR: I'm know very little about power measurement: Do I need to bother about reactive power? If so, how do I measure it?

---

The energy meeter (3-phase, 220v AC) in my apartment has 2 LEDs, and they are labeled as "Active" and "Reactive". So far I could only notice the Active blinking. (I can post a picture of it, if required)

Now I know very little about energy measurement, but I've read a bit about this matter online.
Most of the material is either too simplistic and offers naive comparisons, or is too technical and mention other terms that I also don't have a full grasp of, like the _power factor_, being _inductive_ or _capacitive_, or " reactive bounces back and forth between source and load" (whatever that means)

I do understand that Reactive power is not actually consumed by circuits, so some countries/providers do not charge for this kind of load/"consumption".
Since my meeter does mention it, I'm assuming that my provider does account for it (either direct or indirectly).
I tried [their website](https://translate.google.com/translate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), but information in there is imprecise and confusing (I guess **very few** customers ask these questions), so I really don't know whether or I pay for it.

I'm having a hard time grasping:
- Whether or not I should bother/care about reactive power measurement
- How do I measure reactive power
- Whether or not reading only the active power will be representative of my actual energy usage/footprint
- Understand the core concepts

I'd appreciate if anyone could help me get tho these points, or point me in the right direction.

xorbital, 2021-08-10:
The website you've linked doesn't work for me, however it contains "commercial-industrial", so I'm not sure it applies to you.
Most private consumers won't have to pay for that (directly). Your meter only has one reading on the screen, right?
Reactive Power is the energy lost in transfer. That might be just line resistance (all the hundreds of meters the current needs to travel) or losses in inductive / capacitive circuits. If you want to learn a bit more, I'd recommend watching [this video](https://youtu.be/J86QK0Njfv4) about scam products claiming to reduce your energy bill.
So,

- I don't think you should bother, you could call your energy provider to confirm.
- You could set up two ESP sensors. But maybe the meter isn't even monitoring reactive power.
For an end device you can hook up a power meter, some can read out the reactive power / power factor.
- It'll be good enough. There's line resistance between the street and your house connection, and that doesn't get taken into account, neither does the wiring from your house to the power plant, although you're using 0.001% of it.
There are a lot of losses on the entire grid and nothing works with 100% efficiency, neither power plants, nor wiring, transformation stations nor end devices.
For me anything other than the active power is out of scope.

phrfpeixoto, 2021-08-10:
@xorbital Thank you so much for taking the time to reply here. Electroboom is the best!

That's cool, but I think I'll have to call the provider and try to find the exact info (god help me with that):
I found the [user's manual](https://www.dropbox.com/s/mk1bojvsu1eu8ne/Manual-VECTOR-PA-e-PAR-Nansen.pdf) for [my meter](https://uc25a7403714edc6248a52ddabef.previews.dropboxusercontent.com/p/thumb/ABTHmZUr-U-U77AxJOdnmOcghE8HykAJPce6TWEYS9pb96OSlaIHET_dCFnxlyvgTStFEMtOkreh_fIPqbsF2CYQ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), and everything leads me to believe that some (inductive) reactive power is being measured:

- The faceplate has an indication lead for reactive power, as well as indications on how much energy each pulse accounts for.
- The manual states "To check the accuracy of the device use the LED's or the pulse outputs (KYZ) that emit, all the time, pulses proportional to the measured active and reactive energy."
- The manual contains a section with differential equations for how everything is calculated, and it does include one for Reactive power
- The display information changes every 6s, and among other info, it displays it shows Power Factor and "Total Inductive Power".

Now, all this means that the device is able to measure/monitor reactive power. It does not mean that the provider is actually charging for it. Hence, I have to call them.

The most frustrating thing is that this device is equipped with an async RS485 serial port that outputs the metering information. The manual even details how each payload is structured, but I **strongly** doubt that the provider will let me use that.

I'll go ahead and try to build a HA Glow device, get it installed, and see what measurements I get from it, and how close to the official measurement from the power provider it will be.

phrfpeixoto, 2023-01-25:
=(

klaasnicolaas, 2023-01-25:
@phrfpeixoto ??

phrfpeixoto, 2023-01-26:
Just a sad realization that I still haven't built my sensor because of lacking/misinformation.
The provider simply won't share any meaningful information and even came to lengths of saying that I could be fined if I "tamper" with my meter. Now what is the extent of tampering under their lawyers' understanding, that's a real unknown.

Closed 2023-01-25.

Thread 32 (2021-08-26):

Question about photodiode sensitivity

alemuro, 2021-08-26:
Hello all,

First of all, let me congratule you for this project! 🎉

It's been a long time since I wanted to start playing with some ESP32 devices, and this has been enough to buy one 😋  I received my ESP32 a couple of days ago and I've been doing some testing since today.

The reason I'm opening this issue is because I would like to ask if there is  some way to  change the sensitivity of the photodiode sensor. In spain  we have some sort of methacrylate protecting our  meters, this means there is a gap between the meter light and the photodiode. As far as I could check, this gap is preventing my sensor to properly read data. I manged to emulate this by using my smartphone. I realised it only worked fine when the sensor was stucked to the camera led... but it fails when there is a gap bigger to 1 cm.

So, do you know if there is any chance to change this sensitivity?

Thanks in advance! :)

nigotiator, 2021-08-30:
In Finland we have the same kind of protection but for me it seem to work though. I've compared the total power consumption per day between HA and Energy company and the gap is 1 KWh at the best.
For me the best way to read the sensor was to set it up like this https://ibb.co/R2Hm9v1 so the photodiode is pointing to the energy meter's led... Yeah, I need to print the case :D
Sensor I'm using is this https://www.aliexpress.com/item/32852231949.html

But I  have other issue. The meter has also kvarh (?) led which I guess casues some issues with the reading since I get values like this (4th line) every now and then... kvarh led doesn't blink that often
`
[13:37:25][D][sensor:131]: 'Mittari - Total energy': Sending state 126.89900 kWh with 3 decimals of accuracy
[13:37:26][D][sensor:131]: 'Mittari - Power consumption': Sending state 2926.82910 W with 0 decimals of accuracy
[13:37:26][D][sensor:131]: 'Mittari - Total energy': Sending state 126.90100 kWh with 3 decimals of accuracy
[13:37:26][D][sensor:131]: 'Mittari - Power consumption': Sending state 128571.42969 W with 0 decimals of accuracy
[13:37:28][D][sensor:131]: 'Mittari - Power consumption': Sending state 2880.00000 W with 0 decimals of accuracy
`
Just wondering if there is some way to filter those huge values out...

slovdahl, 2021-09-12:
@nigotiator try adding e.g. `internal_filter: 30ms`. I had similar issues and tinkering with `internal_filter` solved it for me (https://esphome.io/components/sensor/pulse_meter.html#configuration-variables).

nigotiator, 2021-09-12:
> @nigotiator try adding e.g. `internal_filter: 30ms`. I had similar issues and tinkering with `internal_filter` solved it for me (https://esphome.io/components/sensor/pulse_meter.html#configuration-variables).

Thanks for the tip! Currently I have 5ms there so let's try with that!

nigotiator, 2021-09-12:
Yay, looks way better now! Thanks @slovdahl
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

slovdahl, 2021-09-13:
Great!

FWIW, I googled the technical specs of my meter and it said that the LED pulse is 30 ms +- 3 ms long. So technically something like 15 ms should be enough, but not until I changed it from 27 to 30 ms I got rid of all the spurious readings.

klaasnicolaas, 2021-09-16:
Can we close this issue?

alemuro, 2021-09-16:
Sure! All of theses has helped me a lot! Thanks guys 😄
And also I managed to change the sensitivity of the sensor with a screwdriver 😋

Closed 2021-09-16.

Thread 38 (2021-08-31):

Proposal for an all-in-one enclosure

bedfelllow, 2021-08-31:
I flashed this to a Wemos D1 Micro last night and although I have not tested the functionality yet, it flashed OK and it should work as it's an ESP8266. Given the very small size of the Wemos D1 Mini, this led me to think that there is potential for the sensor and MCU to be in a single case, which would be quite a neat solution I think. Unfortunately I'm not skilled at 3D design, but maybe someone in the community could design something?

slovdahl, 2021-09-10:
Is yours really called Wemos D1 Micro? I can't find any references to such a board.

I use [Wemos D1 Mini](https://www.wemos.cc/en/latest/d1/d1_mini.html) and [D1 Mini Pro](https://www.wemos.cc/en/latest/d1/d1_mini_pro.html) myself, so I will at least try to come up with modified cases that fit those two at some point.

bedfelllow, 2021-09-10:
Sorry, I got the name wrong. You are correct, it is a Wemos D1 Mini. I think a case incorporating the Di Mini and the photodiode board would be a great all-in-one solution.

m-s-e, 2021-09-13:
@slovdahl how did you design the cases? If it's Fusion360 I'd be happy to help with taking the design files and creating something for the D1 Mini

slovdahl, 2021-09-13:
> @slovdahl how did you design the cases? If it's Fusion360 I'd be happy to help with taking the design files and creating something for the D1 Mini

I haven't designed anything yet :slightly_smiling_face: I'll try to modify the current ones whenever I can find the time.

Maybe @klaasnicolaas can shed some light on how they were originally designed?

m-s-e, 2021-09-13:
@slovdahl - sorry!! i thought you have designed the original enclosures!! 🤦‍♂️

KixMan28, 2021-09-13:
@m-s-e I modified a little bit the original files, because I use a Geekcreit ESP 12F instead of an ESP32 module. I also modified a photodiode case because it was too loose  for my taste.
[HA Glow.zip](https://github.com/klaasnicolaas/home-assistant-glow/files/7154929/HA.Glow.zip)

bedfelllow, 2021-09-13:
> @m-s-e I modified a little bit the original files, because I use a Geekcreit ESP 12F instead of an ESP32 module. I also modified a photodiode case because it was too loose for my taste.
> [HA Glow.zip](https://github.com/klaasnicolaas/home-assistant-glow/files/7154929/HA.Glow.zip)

Any chance you could share an STL of your photodiode enclosure modification, as I find the one I have printed to be very loose?

It would be even better though if someone was able to create the suggests all-in-one Wemos D1 Mini case.

KixMan28, 2021-09-13:
@bedfelllow see attached the 3MF files.
[Sensor case.zip](https://github.com/klaasnicolaas/home-assistant-glow/files/7155175/Sensor.case.zip)

bedfelllow, 2021-09-13:
> @bedfelllow see attached the 3MF files.
> [Sensor case.zip](https://github.com/klaasnicolaas/home-assistant-glow/files/7155175/Sensor.case.zip)

Great, thank you.

klaasnicolaas, 2021-09-13:
@m-s-e The original case is designed by me 😉
Unfortunately I can't design a case for a Wemos D1 at the moment because I'm out of stock of that board.

m-s-e, 2021-09-14:
all, any thoughts on how the boards might be arranged for an all-in-one enclosure?
on top of each other / side by side / above&below ?

bedfelllow, 2021-09-14:
> all, any thoughts on how the boards might be arranged for an all-in-one enclosure?
> on top of each other / side by side / above&below ?

I initially considered them being on top of each other as that would make a very compact assembly but I'm not sure of the practicalities of wiring the two together in this configuration. It therefore may be easier to have them both at the same level within the enclosure and I also think this would be an easier design.

bedfelllow, 2021-09-14:
A case something on the basis of this may be practical, though it would obviously be a lot shorter: https://cdn-blog.adafruit.com/uploads/2021/01/Wemos-Lolin-D1-Mini-Adafruit-dual-sensor-case-600x400.jpg

bedfelllow, 2021-09-14:
Or maybe something like this but replacing the DHT22 sensor with the photodiode board? https://www.thingiverse.com/thing:4274361

bedfelllow, 2021-09-14:
This seems to be the shorter version of the first link I posted. https://www.thingiverse.com/thing:4711281

bedfelllow, 2021-09-14:
I mashed this together using the sensor case from this project and this one from thingiverse: [https://www.thingiverse.com/thing:4304401](url)

It's obviously not ideal but as a proof of concept it works.

https://i.ibb.co/0ffM4BP/IMG-20210914-220409.jpg

https://i.ibb.co/1qvm5vc/IMG-20210914-220354.jpg

https://i.ibb.co/6FPpfbs/IMG-20210914-220330.jpg

bedfelllow, 2021-09-18:
I've combined the sensor case from this project and a modification of this case [https://www.thingiverse.com/thing:4861266/files](url), cutting the lightning bolt in the lid using this as design: [https://www.thingiverse.com/thing:2553540/files](url) to come up with this:

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

anverx, 2021-09-18:
This project really should live in one small box.  Here is how i wired the photo sensor to an esp32 dev board.  I'm plannig to design a small case for this.  I'm considering a vertical rail so that sticky tape attachment is only on the top surface of the metering device.
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

anverx, 2021-10-18:
oh yeah, that reminds me, i've sill gotta publish mine ;)
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

bedfelllow, 2021-10-18:
Looking forward to trying both of these designs. Thanks.

Closed 2022-01-27.

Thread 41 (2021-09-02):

ESP doesn't boot when DO connected

gcordalis, 2021-09-02:
Just received all my parts and wired it all up.

I've run into an issue where the ESP32 won't boot if DO (on the photodiode) is connected.

If I disconnect the pin it'll boot fine, I can connect to it, HA sees it - all is well minus getting no data from the sensor.

If I connect the pin after boot log output freezes with the below message:
```
[D][sensor:131]: 'House - Total energy': Sending state 3.85000 kWh with 3 decimals of accuracy
[D][light:038]: 'Red' Setting:
[D][light:049]:   State: OFF
```

I've replaced the wires from ESP to photodiode, resoldered the connections, run the ESP from a different power source and reflashed the firmware. I have no idea what else to try - I appreciate this is unlikely to be a glow specific issue but searching around hasn't helped.

Any help would be greatly appreciated!

landmaj, 2021-09-08:
I had the same issue. Try using some other pin, I used D3 instead of D12 and it worked.

landmaj, 2021-09-08:
According to my reseach, GPIO12 is a bootstraping pin and if pulled up it will prevent ESP32 from booting normally (the pin is used to set flash voltage or something). It is best to avoid it and use another pin if possible.

swa72, 2021-09-08:
It worked for me when I changed from 3.3V to 5V.

AndyKassell, 2021-09-12:
Same issue using ESP32 Devkit C module, I moved D0 to GPIO13 (the other side of the GND pin from GPIO 12 on this layout) and all now works as expected.

gcordalis, 2021-09-13:
Thanks everyone.

Turned out the photodiode shipped with the diode soldered to the board the wrong way. removing it and switching the pins around resolved the issue.

First time using ESP32 boards and I certainly was not expecting my first issue to be a hardware related mistake...

Closed 2021-09-13.

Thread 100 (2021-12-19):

Block my pi  during compile

caaveiro, 2021-12-19:
Hello.

I have completely done this project (3d printing / printed circuit) but I run into a problem when trying to install it from EspHome.

With the file home_assistant_glow.yaml it blocks my opi when trying to compile it. Can there be any problems with the configuration or dependencies of the file?
Any other project I do in esphome always works for me and compiles perfectly.

The log is as follows:

-------------------------------------------------- -----------------------------------------
INFO Reading configuration /config/home_assistant_glow.yaml ...
WARNING GPIO2 is a Strapping PIN and should be avoided.
Attaching external pullup / down resistors to strapping pins can cause unexpected failures.
See https://esphome.io/guides/faq.html#why-am-i-getting-a-warning-about-strapping-pins
WARNING GPIO4 is a Strapping PIN and should be avoided.
Attaching external pullup / down resistors to strapping pins can cause unexpected failures.
See https://esphome.io/guides/faq.html#why-am-i-getting-a-warning-about-strapping-pins
INFO Generating C ++ source ...
INFO Compiling app ...
Processing home-assistant-glow (board: nodemcu-32s; framework: arduino; platform: platformio / espressif32 @ 3.3.2)
-------------------------------------------------- ------------------------------
HARDWARE: ESP32 240MHz, 320KB RAM, 4MB Flash
Dependency Graph
| - <AsyncTCP-esphome> 1.2.2
| - <WiFi> 1.0
| - <FS> 1.0
| - <Update> 1.0
| - <ESPAsyncWebServer-esphome> 2.1.0
| | - <AsyncTCP-esphome> 1.2.2
| - <DNSServer> 1.1.0
| - <ArduinoJson-esphomelib> 5.13.3
| - <Improv> 1.0.0
| - <ESPmDNS> 1.0
Compiling .pioenvs / home-assistant-glow / src / esphome / components / api / api_connection.cpp.o
Compiling .pioenvs / home-assistant-glow / src / esphome / components / api / api_frame_helper.cpp.o
Compiling .pioenvs / home-assistant-glow / src / esphome / components / api / api_pb2.cpp.o
Compiling .pioenvs / home-assistant-glow / src / esphome / components / api / api_pb2_service.cpp.o

-------------------------------------------------- ---------------------------------
And from there the process is totally blocked, I have tried to leave it for hours, in case it was a very long process, but I have not achieved absolutely anything after 7-8 hours of waiting ...

klaasnicolaas, 2021-12-20:
Your logs look normal and I don't think there is anything wrong with the yaml file. Compiling is usually done in 5 minutes, which should not take hours. Alternatively you could use ESP web tools via this website, then you install the firmware via the browser on your ESP instead of compiling everything yourself. https://klaasnicolaas.github.io/home-assistant-glow

Helmasynti, 2021-12-21:
Have you tried removing the LED from GPIO2 and GPIO4? My ESP could not enter flash mode before I did that.

klaasnicolaas, 2021-12-21:
That would also be a good solution, although the problem is already with compiling the firmware. Which version of ESPHome are you using?

sfritz67, 2021-12-24:
I had same issue on RPi3, crash when compiling, no response... it came from not enough capacity.
I had a RPI4 2Gb for another project, tried with it, and it worked.

caaveiro, 2021-12-25:
Hello.
It seems that the problem is memory capacity (I have an orange pi with 512 Mb of ram). Searching in forums I have found people had the same problem and it always seemed to be the same problem: lack of ram memory.
I have solved it temporarily by creating a debian virtual machine in windows 10 with the Hyper-v software, it allowed me to compile perfectly.
On the other hand, I have ordered the purchase of a Rpi4 2gb ram to transfer the installation of home assistan and esphome.

caaveiro, 2022-01-14:
I write this message to inform that after installing the Rpi 4 and testing the system everything works OK ...
I had an Orange PI Lit 512 Mb of ram and it seems that it is very little ram memory for projects that have a considerable size like this ... for simple projects it worked correctly ...

smulle48, 2022-04-01:
My rpi4 with 2gb ram kept locking up during compile.

I've found out that the Debian supervised install om HA did not have any swap file. After following this guide, it compiled just fine and didn't crash :-)

https://linuxize.com/post/how-to-add-swap-space-on-debian-10/

Closed 2022-02-20.

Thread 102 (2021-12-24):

Not registering anything?

thehiddentruth, 2021-12-24:
I'm trying to understand, why it's not registering any data.

When I use my phones flash to trigger the photodiode, the D0 led blinks, but nothing gets registeret, neither in the logs nor in HA.

**Setup looks like this**
- Wemos D1 Mini Lite
- 3.3V -> VCC
- GND -> GND
- D2 -> D0

**My ESPHome yaml looks like this**

```yaml
substitutions:
  device_name: energy
  friendly_name: House
  device_description: "Measure your energy consumption with the pulse LED on your smart meter"
  pulse_pin: GPIO4
  status_led: GPIO5

  pulse_rate: '1000'

  web_username: 'glow'
  web_password: 'esphome'

esphome:
  name: '${device_name}'

esp8266:
  board: d1_mini_lite

wifi:
  ssid: !secret wifi_ssid
  password: !secret wifi_password

output:
  - platform: gpio
    pin: GPIO2
    id: output_red
  - platform: gpio
    pin: GPIO4
    id: output_green

light:
  - platform: binary
    internal: true
    id: led_red
    name: Red
    output: output_red

status_led:
  pin:
    number: ${status_led}

text_sensor:
  - platform: version
    hide_timestamp: true
    name: '${friendly_name} - ESPHome Version'
  - platform: wifi_info
    ip_address:
      name: '${friendly_name} - IP Address'
      icon: mdi:wifi
    ssid:
      name: '${friendly_name} - Connected SSID'
      icon: mdi:wifi-strength-2

sensor:
  - platform: pulse_meter
    id: energy_pulse_meter
    name: '${friendly_name} - Power consumption'
    unit_of_measurement: 'W'
    state_class: measurement
    device_class: power
    icon: mdi:flash-outline
    accuracy_decimals: 0
    pin: ${pulse_pin}
    on_value:
      then:
        - light.turn_on:
            id: led_red
        - delay: 0.5s
        - light.turn_off:
            id: led_red
    filters:
      - lambda: return x * ((60.0 / ${pulse_rate}) * 1000.0);
    total:
      name: '${friendly_name} - Total energy'
      unit_of_measurement: 'kWh'
      icon: mdi:circle-slice-3
      state_class: total_increasing
      device_class: energy
      accuracy_decimals: 3
      filters:
        - lambda: return x * (1.0 / ${pulse_rate});
```

Any idea why nothing gets registered?

klaasnicolaas, 2021-12-25:
You now have the pulse led and status led both on GPIO4, set the pulse led to D6 (GPIO12) 😉

thehiddentruth, 2021-12-25:
> You now have the pulse led and status led both on GPIO4, set the pulse led to D6 (GPIO12) 😉

You're right. But I originally had it on D6 (GPIO12) as the documentation said, but still the exact same thing? No readings at all. I changed there GPIO because I thought that the D6 was damaged or something..

I also checked to make sure that the photodiode is soldered correctly, as per documentation.

klaasnicolaas, 2021-12-26:
Have you tried another cable? Or another ESP?

thehiddentruth, 2021-12-27:
> Have you tried another cable? Or another ESP?

Yes, I have tried both with an wemos d1 mini and an esp32, and with 3 different micro USB cables. Exact same.. no readings at all

klaasnicolaas, 2021-12-27:
What color is the pulse LED? Your issue might be similar to this one #62?

thehiddentruth, 2021-12-28:
> What color is the pulse LED? Your issue might be similar to this one #62?

I haven't connected the RGB diode, as I don't have one.

Could that be the issue? That I haven't connected an RGB diode?

klaasnicolaas, 2021-12-28:
I don't think that has anything to do with each other.

Closed 2022-02-04.

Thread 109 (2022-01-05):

Can a Photo Resistor be used instead of a Photodiode?

dweng0, 2022-01-05:
Hi, Resistors tend to be more sensitive to light, that said, would a breakout board with a resistor instead of a diode be a viable option? can the values in the script be tweaked to accommodate for it?

Jay

klaasnicolaas, 2022-01-05:
You can use a photoresistor with the glow, it is recommended to use the [internal_filter](https://github.com/klaasnicolaas/home-assistant-glow/blob/main/home_assistant_glow.yaml#L133) option because of higher sensitivity.

dweng0, 2022-01-06:
Just looking at the theory here, but [a simple photoresistor](https://nl.banggood.com/search/photoresistor.html?from=nav) hooked from an esp32board (5v) to a [5kohm resistor](https://www.ebay.co.uk/itm/263894047668) and back to the board (gnd).

We can then measure the connection between the photoresistor and the fixed resistor by connecting a wire to their connection and giving it to an Analogue input, for example (P12).

couple this with a [small breadboard](https://www.ebay.co.uk/itm/284000081310)
and some [jumper lead wires](https://www.ebay.co.uk/itm/261998236967?epid=1342511679&hash=item3d004fd527:g:98MAAOSwnK9ZXMIP)

And you have an entry-level friendly reader and it doesn't 'matter which way round the resistors are

(Had a photodiode that was soldered the wrong way, and I suck at soldering!).

raforo, 2022-01-06:
I'm interested in alternatives to the recommended photodiodes, I've bought three at Banggood, they all arrived with the polarity changed, I soldered correctly, but I cannot adjust the sensitivity to the meter's LED, it seems that it is very dim and goes from giving a continuous signal in DO to give no signal in DO when moving the variable resistor.
Everything else works perfectly, but I cannot adjust the sensitivity of the Led , a strong light like a flashlight It's detected, but the LED does not.
Any advice? Thanks

dweng0, 2022-01-06:
Is the solder connection good? a weak signal can mean that the circuit is not sound, likely cause being the soldering or the pins being loose

raforo, 2022-01-06:
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

Have you made and tested your scheme?
I don't understand where to connect pin 12 of esp32?
Would it work connecting to the 3.3V output instead of the 5V output of the esp32?

dweng0, 2022-01-06:
> I don't understand where to connect pin 12 of esp32?
GPIO12
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

You can technically connect it to any ADC pin (Analogue to digital conversion) I picked 12 because that's what the code in this repo reads its input from. Otherwise, you'll have to modify the code to read from a different pin.

>Would it work connecting to the 3.3V output instead of the 5V output of the esp32?
3.3v would require a 3.3vresistor instead of the 5v one, but in theory, it will work, the values would of course be different, and
@klassnicolas mentioned that the following line would need to be uncommented in the scheme to accommodate the additional sensitivity:

https://github.com/klaasnicolaas/home-assistant-glow/blob/main/home_assistant_glow.yaml#L133

raforo, 2022-01-06:
>

> > I don't understand where to connect pin 12 of esp32?
>
> GPIO12, sometimes called P12 or just 12 (pin 12) on esp32 boards

Thank you very much, I know where pin 12 is, I mean where to connect the other side, reviewing your scheme, I think is in the joining between the photodiode and the 5k ohm resistor. I apologize for my english

raforo, 2022-01-12:
I've replaced the photodiode by an LDR on the Bangood board and it has started working properly, now it detects the pulse of the red LED of the meter without problem.

Thanks

Closed 2022-02-19.

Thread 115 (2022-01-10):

Power Consumption very low? Reasons?

snipah, 2022-01-10:
Hi and thanks for your brilliant work on this one! I built this a proposed and I seems to work just fine: Values seems to be consistent at first glance in the range between 160 - 280 watts. My problem: Even when using the water boiler or the electric stove, consumption goes up but never reaches expected values. Am I interpreting the values in a wrong way? Is this current consumtion per second or does the period of time vary in which this amount of energy in being consumed?

My meter is an eHZ-IW8 with 10.000 imp./kWh. The configuration is amended accordingly

```yaml
substitutions:
  device_name: home-assistant-glow
  friendly_name: House
  device_description: "Measure your energy consumption with the pulse LED on your smart meter"
  pulse_pin: GPIO12
  status_led: GPIO5

  imp/kWh rate ⬇ #
  pulse_rate: '10000.0'

  Webserver credentials ⬇ #
  web_username: 'snip'
  web_password: 'snap'

dashboard_import:
  package_import_url: github://klaasnicolaas/home-assistant-glow/home_assistant_glow.yaml

esphome:
  name: '${device_name}'
  comment: '${device_description}'
  project:
    name: "klaasnicolaas.home_assistant_glow"
    version: "3.0.0"
  platform: ESP8266
  board: nodemcuv2

WiFi credentials #
wifi:
  ssid: 'snip-snap'       # Enter your WiFi SSID here. Example: `ssid: 'your_network_name'`
  password: 'snap-snip'   # Enter your wifi password here. Example: `password: 'abcde123456'`

  Enable fallback hotspot (captive portal) in case wifi connection fails
  ap:
   ssid: '${device_name}'

captive_portal:

Enable logging
logger:

Enable improv over serial
improv_serial:

Enable Home Assistant API
api:
  services:
    - service: reset_total_energy
      then:
        - button.press:
            id: button_reset_total

ota:
  safe_mode: true
  reboot_timeout: 10min
  num_attempts: 5

web_server:
  port: 80
  auth:
    username: '${web_username}'
    password: '${web_password}'

output:
 #-# platform: gpio
    #pin: GPIO5
    #id: output_blue
  - platform: gpio
    pin: GPIO2
    id: output_red
  - platform: gpio
    pin: GPIO4
    id: output_green

light:
  - platform: binary
    internal: true
    id: led_red
    name: Red
    output: output_red

Status LED for connection
status_led:
  pin:
    # Blue LED
    number: ${status_led}

button:
  - platform: restart
    name: "Restart - Glow"
  - platform: template
    name: "Reset - Total Energy"
    id: button_reset_total
    on_press:
      - pulse_meter.set_total_pulses:
          id: sensor_energy_pulse_meter
          value: 0

Sensors for ESP version and WIFI information
text_sensor:
  - platform: version
    hide_timestamp: true
    name: '${friendly_name} - ESPHome Version'
  - platform: wifi_info
    ip_address:
      name: '${friendly_name} - IP Address'
      icon: mdi:wifi
    ssid:
      name: '${friendly_name} - Connected SSID'
      icon: mdi:wifi-strength-2

sensor:
 WiFi signal
  - platform: wifi_signal
    name: "${friendly_name} - WiFi Signal"
    update_interval: 120s

 Pulse meter
  - platform: pulse_meter
    name: '${friendly_name} - Power Consumption'
    id: sensor_energy_pulse_meter
    unit_of_measurement: 'W'
    state_class: measurement
    device_class: power
    icon: mdi:flash-outline
    accuracy_decimals: 0
    pin: ${pulse_pin}
    internal_filter: 100ms
    on_value:
      then:
        - light.turn_on:
            id: led_red
        - delay: 0.05s
        - light.turn_off:
            id: led_red
    filters:
      - lambda: return x * ((60.0 / ${pulse_rate}) * 1000.0);
    total:
      name: '${friendly_name} - Total Energy'
      id: sensor_total_energy
      unit_of_measurement: 'kWh'
      icon: mdi:circle-slice-3
      state_class: total_increasing
      device_class: energy
      accuracy_decimals: 3
      filters:
        - lambda: return x * (1.0 / ${pulse_rate});
   Total day useage
  - platform: total_daily_energy
    name: '${friendly_name} - Daily Energy'
    id: sensor_total_daily_energy
    power_id: sensor_energy_pulse_meter
    unit_of_measurement: 'kWh'
    icon: mdi:circle-slice-3
    state_class: total_increasing
    device_class: energy
    accuracy_decimals: 3
    filters:
      # Multiplication factor from W to kW is 0.001
      - multiply: 0.001

Enable time component to reset energy at midnight
time:
  - platform: sntp
    id: my_time`
```
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
snipah, 2022-01-10:
> How bad is the difference between what the Glow measures and what you expect?

I simply think that e. g. a water heater uses a signifikant amount of energy (up to 3.000 Watts). If I use such devices, it does not show in the current consumption. At night I would expect a comsumption at around 150W, but during the day I would expect up to 500W in average: Cooking, 2 PCs with monitors, etc.

Helmasynti, 2022-01-12:
10.000 imp/kWh is a lot of impulses per kWh. On the other hand, as far as I understand, your internal_filter allows max ten impulses per second, which makes 3,6kW, so you cannot get readings higher than that.

snipah, 2022-01-12:
Yeah, deleted the filter after noticing this before... does not help: Consumption remains unchanged.

@klaasnicolaas I would expect a consumption up to 1000W while using a water heater or a stove for preparing meals...
Is there any limitation to the number of pulses the hardware can register per minute/ second?

klaasnicolaas, 2022-01-12:
You would expect that indeed.

As far as I know there is no limit in the number of pulses, but 10.000 imp/kWh is the most extreme I've seen in the issues so far. The only question is how are you going to find out where this limit should be 🤔

I see someone on the forum with the same pulse rate: https://community.home-assistant.io/t/fail-to-install-home-assistant-glow/343948

Helmasynti, 2022-01-14:
I would imagine that 10.000 imp/kWh means also that each pulse is very short. At the consumption rate 10 kW the meter gives around 27 pulses per second which means that one pulse cannot be longer than 0,03 seconds. Could this be an issue? That every pulse is not registered due to their short duration? Have you tried tinkering with the sensitivity potentiometer? If you increase sensitivity, try somehow to block all the light coming from the led in the photodiode board to prevent interference. The 3D printed case for the diode is well designed to prevent that from happening but maybe you could use black tape or something like that in addition.

snipah, 2022-01-15:
Yep, tinkered with the pots a lot and once the sensitivity get too high, values are all over the place. The whole diode is very well blocked from other light sources with black tape... does not help. The internal_filter is removed, but it makes no difference. Maximum consumption is around 270W, no matter which other devices I switch on for testing purposes. Any other ideas?

Helmasynti, 2022-01-15:
The green led on the photodiode board blinks every time it detects a pulse. It can be used to check whether the board registers every pulse. If it does not, the problem is in the photodiode board.

henne49, 2022-01-19:
Same here, I have this https://emh-metering.com/produkte/haushaltszaehler-smart-meter/ehz-p/ and it also uses 10000 impules per 1kwh. I'm also stuck with 203 W when overall it should be 600, what I get from my inverter. As I have to powermeter one for household and 1 for heating. I want to measure household only and then computing the consumption for heating. Anyway...
what I wanted to say 3600W max would be fine for me, does it make sense to use any thing on the filter like 30 ms as this is the max pulses per second, as @Helmasynti  outlined?

dlaidig, 2022-03-13:
Are you sure that you are using the correct IR LED? I have a similar power meter which has two regularly blinking IR LEDs:

1. a digital interface (sending long messages that are clearly visible via a phone camera, every 1 to 4 seconds depending on the current power consumption)
2. a 10000 impulse/kWh LED (with a pulse length of 5 ms, totally invisible via a phone camera)

Details can be found in the (German) manual: https://emh-metering.com/wp-content/uploads/2020/08/eHZ-K-BIA-D-1-20.pdf (on page 10, 3 is the correct LED with "IR" written next to it, 5 is the digital interface).

It is quite confusing that the sending frequency of the digital interface also depends on the current power consumption. The maximum frequency of 1 pulse per second should lead to a maximum power measurement of 360 W, which is quite similar to what you saw.

Since the pulse duration of the real IR led is 5 ms, I have set `internal_filter: 10ms` which seems to work quite reliably so far.

henne49, 2022-03-13:
never got it working and started to use tasmota firmware and using the hichi reader it works very well and both directions.

https://www.ebay.de/itm/313460034498

snipah, 2022-03-13:
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

Wow! This is embarrassing! You are totally right! When doing the initial install, I took a digital cam and attached the sensor to the blinking LED, which was obviously the wrong LED. Now it's working perfectly! Thanks a lot!

Closed 2022-04-21.

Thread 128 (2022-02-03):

Maximum cable length from photodiode to ESP?

EspressoNerd, 2022-02-03:
Due to low WiFi signal strength I need to place the ESP away from the photodiode. What is the maximum cable length for the connection of the ESP and the photodiode? I am aware that this isn't a fixed length (0,9m is ok, 1 m isn't), but at least an order of magnitude would be good; e.g. is 2 m ok?

Kimble8650, 2022-02-07:
I'd say, that 2m is probably fine. Especially if you don't have any large sources of EM-interference nearby. If voltage drop becomes an issue (it prob. won't), just use a thicker wire.

EspressoNerd, 2022-02-09:
Thank you, great news.

Kimble8650, 2022-02-23:
To elaborate a bit further on the topic; some users have reported spikes in the reported power consumption, which might be due to EM-interference caused by the power meter itself. Many power meters nowadays have remote consumption reporting, and send their data over an RF link.

So stuff you can do to mitigate this is to route your cable avoiding the antennae in the power meter, use a shielded cable, place a filtering capacitor between the impulse-pin and ground and add some kind of internal filter value to the configuration (maybe 100ms or so. depending on the impulse rate of your power meter).

Closed 2022-04-02.

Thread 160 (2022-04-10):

installation flash problem

Jan140cz, 2022-04-10:
INFO Reading configuration /config/esphome/home_assistant_glow.yaml...
WARNING GPIO2 is a Strapping PIN and should be avoided.
Attaching external pullup/down resistors to strapping pins can cause unexpected failures.
See https://esphome.io/guides/faq.html#why-am-i-getting-a-warning-about-strapping-pins
WARNING GPIO4 is a Strapping PIN and should be avoided.
Attaching external pullup/down resistors to strapping pins can cause unexpected failures.
See https://esphome.io/guides/faq.html#why-am-i-getting-a-warning-about-strapping-pins
WARNING GPIO12 is a Strapping PIN and should be avoided.
Attaching external pullup/down resistors to strapping pins can cause unexpected failures.
See https://esphome.io/guides/faq.html#why-am-i-getting-a-warning-about-strapping-pins
INFO Detected timezone 'Europe/Prague'
INFO Generating C++ source...
INFO Compiling app...
Processing home-assistant-glow (board: nodemcu-32s; framework: arduino; platform: platformio/espressif32 @ 3.5.0)

HARDWARE: ESP32 240MHz, 320KB RAM, 4MB Flash
LDF: Library Dependency Finder -> https://bit.ly/configure-pio-ldf
Dependency Graph
|-- 1.2.2
|-- 1.0
|-- 1.0
|-- 1.0
|-- 2.1.0
| |-- 1.2.2
|-- 1.1.0
|-- 1.0
|-- 6.18.5
|-- 1.2.1
Compiling /data/home-assistant-glow/.pioenvs/home-assistant-glow/src/main.cpp.o
Linking /data/home-assistant-glow/.pioenvs/home-assistant-glow/firmware.elf
RAM: [= ] 12.8% (used 42020 bytes from 327680 bytes)
Flash: [===== ] 54.2% (used 994414 bytes from 1835008 bytes)
Building /data/home-assistant-glow/.pioenvs/home-assistant-glow/firmware.bin
esp32_create_combined_bin(["/data/home-assistant-glow/.pioenvs/home-assistant-glow/firmware.bin"], ["/data/home-assistant-glow/.pioenvs/home-assistant-glow/firmware.elf"])
Wrote 0x102ce0 bytes to file /data/home-assistant-glow/.pioenvs/home-assistant-glow/firmware-factory.bin, ready to flash to offset 0x0
======================== [SUCCESS] Took 120.97 seconds ========================
INFO Successfully compiled program.
esptool.py v3.2
Serial port /dev/ttyUSB0
Connecting...........
Chip is ESP32-D0WDQ6 (revision 1)
Features: WiFi, BT, Dual Core, 240MHz, VRef calibration in efuse, Coding Scheme None
Crystal is 40MHz
MAC: 58:bf:25:82:84:ac
Uploading stub...
Running stub...
Stub running...
Changing baud rate to 460800
Changed.
WARNING: Failed to communicate with the flash chip, read/write operations will fail. Try checking the chip connections or removing any other hardware connected to IOs.
Configuring flash size...
Warning: Could not auto-detect Flash size (FlashID=0xffffff, SizeID=0xff), defaulting to 4MB
Flash will be erased from 0x00010000 to 0x00102fff...
Flash will be erased from 0x00001000 to 0x00005fff...
Flash will be erased from 0x00008000 to 0x00008fff...
Flash will be erased from 0x0000e000 to 0x0000ffff...
Compressed 994528 bytes to 570070...

A fatal error occurred: Packet content transfer stopped (received 8 bytes)
INFO Upload with baud rate 460800 failed. Trying again with baud rate 115200.
esptool.py v3.2
Serial port /dev/ttyUSB0
Connecting....
Chip is ESP32-D0WDQ6 (revision 1)
Features: WiFi, BT, Dual Core, 240MHz, VRef calibration in efuse, Coding Scheme None
Crystal is 40MHz
MAC: 58:bf:25:82:84:ac
Uploading stub...
Running stub...
Stub running...
WARNING: Failed to communicate with the flash chip, read/write operations will fail. Try checking the chip connections or removing any other hardware connected to IOs.
Configuring flash size...
Warning: Could not auto-detect Flash size (FlashID=0xffffff, SizeID=0xff), defaulting to 4MB
Flash will be erased from 0x00010000 to 0x00102fff...
Flash will be erased from 0x00001000 to 0x00005fff...
Flash will be erased from 0x00008000 to 0x00008fff...
Flash will be erased from 0x0000e000 to 0x0000ffff...
Compressed 994528 bytes to 570070...

A fatal error occurred: Packet content transfer stopped (received 8 bytes)

klaasnicolaas, 2022-04-10:
?? Without some additional information we cannot help you further.

Jan140cz, 2022-04-11:
if the student just throws an error at esp

klaasnicolaas, 2022-04-11:
When did it go wrong, what hardware did you have connected?  What have you already tried to solve it yourself?  Again without additional information I cannot help you further.

Jan140cz, 2022-04-11:
broke after inhalation to esp32.  hardware: esp32, 4 - pin photodiode module light brightness detection photoelectric switch intelligent car board
![Uploading BDC71233-58C2-448D-B3C9-C3DE83110CD4.jpeg…]()

klaasnicolaas, 2022-04-11:
Have you tried flashing without the photodiode board connected? Flashing may fail as long as it is connected during this process.

Jan140cz, 2022-04-12:
It didn't have to look like everything went well now

Jan140cz, 2022-04-12:
kiz mail so statues you know unavailable. INFO Reading configuration /config/esphome/home_assistant_glow.yaml...
WARNING GPIO2 is a Strapping PIN and should be avoided.
Attaching external pullup/down resistors to strapping pins can cause unexpected failures.
See https://esphome.io/guides/faq.html#why-am-i-getting-a-warning-about-strapping-pins
WARNING GPIO4 is a Strapping PIN and should be avoided.
Attaching external pullup/down resistors to strapping pins can cause unexpected failures.
See https://esphome.io/guides/faq.html#why-am-i-getting-a-warning-about-strapping-pins
WARNING GPIO12 is a Strapping PIN and should be avoided.
Attaching external pullup/down resistors to strapping pins can cause unexpected failures.
See https://esphome.io/guides/faq.html#why-am-i-getting-a-warning-about-strapping-pins
INFO Detected timezone 'Europe/Prague'
INFO Starting log output from /dev/ttyUSB0 with baud rate 115200
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

Jan140cz, 2022-04-12:
Leaving...
Hard resetting via RTS pin...
INFO Successfully uploaded program.
INFO Starting log output from /dev/ttyUSB0 with baud rate 115200
[05:03:40][I][logger:214]: Log initialized
[05:03:40][C][status_led:014]: Setting up Status LED...
[05:03:40][C][ota:461]: There have been 5 suspected unsuccessful boot attempts.
[05:03:40][D][esp32.preferences:114]: Saving preferences to flash...
[05:03:40][E][ota:468]: Boot loop detected. Proceeding to safe mode.
[05:03:40][I][app:029]: Running through setup()...
[05:03:40][C][wifi:037]: Setting up WiFi...
[05:03:40][C][wifi:201]: Setting up AP...
[05:03:40][C][wifi:203]:   AP SSID: 'home-assistant-glow'
[05:03:40][C][wifi:204]:   AP Password: ''
[05:03:40][C][wifi:213]:   IP Address: 192.168.4.1
[05:03:40][C][ota:085]: Over-The-Air Updates:
[05:03:40][C][ota:086]:   Address: home-assistant-glow.local:3232
[05:03:40][W][ota:095]: Last Boot was an unhandled reset, will proceed to safe mode in 0 restarts
[05:03:40][I][app:062]: setup() finished successfully!
[05:03:40][I][ota:480]: Waiting for OTA attempt.
[05:03:40][I][app:102]: ESPHome version 2022.3.2 compiled on Apr 12 2022, 04:48:57
[05:03:40][I][app:104]: Project klaasnicolaas.home_assistant_glow version 3.0.0
[05:03:40][C][logger:233]: Logger:
[05:03:40][C][logger:234]:   Level: DEBUG
[05:03:40][C][logger:235]:   Log Baud Rate: 115200
[05:03:40][C][logger:236]:   Hardware UART: UART0
[05:03:40][C][status_led:019]: Status LED:
[05:03:40][C][status_led:020]:   Pin: GPIO5
[05:03:40][C][captive_portal:088]: Captive Portal:
[05:03:40][C][wifi:491]: WiFi:
[05:03:40][C][wifi:353]:   Local MAC: 58:BF:25:82:84:AC
[05:03:40][C][wifi:354]:   SSID: ''[redacted]
[05:03:40][C][wifi:355]:   IP Address: 0.0.0.0
[05:03:40][C][wifi:357]:   BSSID: 00:00:00:00:00:00[redacted]
[05:03:40][C][wifi:358]:   Hostname: 'home-assistant-glow'
[05:03:40][C][wifi:360]:   Signal strength: 0 dB ▂▄▆█
[05:03:40][C][wifi:364]:   Channel: 1
[05:03:40][C][wifi:365]:   Subnet: 0.0.0.0
[05:03:40][C][wifi:366]:   Gateway: 0.0.0.0
[05:03:40][C][wifi:367]:   DNS1: 0.0.0.0
[05:03:40][C][wifi:368]:   DNS2: 0.0.0.0
[05:03:40][C][mdns:084]: mDNS:
[05:03:40][C][mdns:085]:   Hostname: home-assistant-glow
[05:03:40][C][ota:085]: Over-The-Air Updates:
[05:03:40][C][ota:086]:   Address: home-assistant-glow.local:3232
[05:03:40][W][ota:095]: Last Boot was an unhandled reset, will proceed to safe mode in 0 It looks like it's still installed just doesn't connect to Wi-Fi

Jan140cz, 2022-04-12:
thank you for the help everything is fine now

Closed 2022-04-12.

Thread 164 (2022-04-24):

GPIO12 causes ESP boot issue

clough360, 2022-04-24:
Using GPIO12 for the sensing LED interferes with the boot process as it is a strapping pin.
The compilation process also warns about this:
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

This caused an issue for me where the device would boot only intermittently with GPIO12 connected. When I switched to GPIO13, the issue device booted (and worked) correctly.

I suggest changing the default yaml config file and related documentation to use GPIO13

klaasnicolaas, 2022-04-24:
Seems like a good plan, I have no idea whether GPIO13 is better, but that something needs to be changed, that's one thing for sure.

smarquard, 2022-05-27:
For me GPIO12 caused the OTA update to fail. I switched to GPIO5 which resolved the issue. It would be good to change the default to something else.

anoadragon453, 2022-07-26:
FYI `GPIO15` was also a strapping pin on my board. `GPIO16` was not, however.

Closed 2022-11-12.

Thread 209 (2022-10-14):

Add Bluetooth proxy?

apazosg, 2022-10-14:
Just wondering if it's possible to add the new Bluetooth proxy functionality.
I added:
Bluetooth_proxy:
  Active: true

But it's not getting detected in ha

m-s-e, 2022-10-14:
this is a nice idea. i didn't realise that you could use and ESPhome device (that was doing other things, like the Glow) as a BT proxy.

klaasnicolaas, 2022-10-14:
Sounds like a great addition, I'll give it a try in my own test environment 😄

If it comes to the point that we add it to the yaml file, then I think it is also useful to make a separate yaml file for it, since for example a wemos / esp8266 does not have bluetooth 🤔

ABredhauer, 2022-10-18:
> Just wondering if it's possible to add the new Bluetooth proxy functionality. I added: Bluetooth_proxy: Active: true
>
> But it's not getting detected in ha

Based on the code here: https://github.com/esphome/bluetooth-proxies/

I think you also need to add the ble_tracker dependency
esp32_ble_tracker:
  scan_parameters:
    interval: 1100ms
    window: 1100ms
    active: true

kirilldem, 2022-10-22:
HA Glow is my first ESPhome device - is it possible to add other sensors on it? can I for example connect a temperature probe to it and report that back to HA? Or scan for my phone's BT signal?

klaasnicolaas, 2022-10-23:
@kirilldem Yes that is all possible

kirilldem, 2022-10-30:
> @kirilldem Yes that is all possible

Thanks! Any pointers where to look or what to search for, googling didn't get me far.

njsaunders, 2022-11-02:
Same here - Just tried to enable Bluetooth proxy but now its ONLY a bluetooth proxy?

Config:

```
---
# Home Assistant Glow
#
# Read your electricity meter by means of the pulse LED on your
# meter, useful if you do not have a serial port (P1).
#
substitutions:
  device_name: home-assistant-glow
  friendly_name: House
  device_description: "Measure your energy consumption with the pulse LED on your smart meter"
  pulse_pin: GPIO12
  status_led: GPIO5
  # imp/kWh rate ⬇ #
  pulse_rate: '1000'

esphome:
  name: '${device_name}'
  comment: '${device_description}'
  project:
    name: "klaasnicolaas.home_assistant_glow"
    version: "3.1.0"
  platform: ESP32
  board: nodemcu-32s

bluetooth_proxy:
  active: true

esp32_ble_tracker:
  scan_parameters:
    interval: 1100ms
    window: 1100ms
    active: true

wifi:
  ssid: !secret wifi_ssid
  password: !secret wifi_password

  # Enable fallback hotspot (captive portal) in case wifi connection fails
  ap:
    ssid: '${device_name}'
    password: !secret fallback_password

captive_portal:

# Enable logging
logger:

# Enable Home Assistant API
api:
  password: !secret esphome_api_password

ota:
  safe_mode: true
  reboot_timeout: 10min
  num_attempts: 5

web_server:
  port: 80
  auth:
    username: !secret esphome_web_username
    password: !secret esphome_web_password

output:
  # - platform: gpio
  #   pin: GPIO5
  #   id: output_blue
  - platform: gpio
    pin: GPIO2
    id: output_red
  - platform: gpio
    pin: GPIO4
    id: output_green

light:
  - platform: binary
    internal: true
    id: led_red
    name: Red
    output: output_red

# Status LED for connection
status_led:
  pin:
    # Blue LED
    number: ${status_led}

# Sensors for ESP version and WIFI information
text_sensor:
  - platform: version
    hide_timestamp: true
    name: "${friendly_name} - ESPHome Version"
  - platform: wifi_info
    ip_address:
      name: "${friendly_name} - IP Address"
      icon: mdi:wifi
    ssid:
      name: "${friendly_name} - Connected SSID"
      icon: mdi:wifi-strength-2

sensor:
  - platform: pulse_meter
    name: '${friendly_name} - Power consumption'
    unit_of_measurement: 'W'
    state_class: measurement
    device_class: power
    icon: mdi:flash-outline
    accuracy_decimals: 0
    pin: ${pulse_pin}
    # internal_filter: 100ms
    on_value:
      then:
        - light.turn_on:
            id: led_red
        - delay: 0.5s
        - light.turn_off:
            id: led_red
    filters:
      # multiply value = (60 / imp value) * 1000
      # - multiply: 60
      - lambda: return x * ((60.0 / ${pulse_rate}) * 1000.0);
    total:
      name: '${friendly_name} - Total energy'
      unit_of_measurement: 'kWh'
      icon: mdi:circle-slice-3
      state_class: total_increasing
      device_class: energy
      accuracy_decimals: 3
      filters:
        # multiply value = 1 / imp value
        # - multiply: 0.001
        - lambda: return x * (1.0 / ${pulse_rate});
 ```

klaasnicolaas, 2022-11-02:
As far as I know it doesn't mean it's just a bluetooth proxy, it's just an extra option you add to it. So you should also be able to connect other sensors to it. Have decided to not add this as standard to the glow for the time being, this due to the fact that you have to hang the ESP on the laptop to flash if you want to use the bluetooth proxies (can update OTA afterwards).

kirilldem, 2022-11-03:
> As far as I know it doesn't mean it's just a bluetooth proxy, it's just an extra option you add to it. So you should also be able to connect other sensors to it. Have decided to not add this as standard to the glow for the time being, this due to the fact that you have to hang the ESP on the laptop to flash if you want to use the bluetooth proxies (can update OTA afterwards).

Do you mean that you will have to re-flash the device with a cable again?

Would you mind sharing an optional config of what it would look like, so the adventurous of us can do it :)

ABredhauer, 2022-11-10:
I've succesfully added BT proxy support to my glow by adding this section to the bottom of the YAML. I don't see the HA glow show up as a bluetooth device but looking at some of my ibeacons now show up the glow as the event source so confident its working

```
esp32_ble_tracker:
  scan_parameters:
    interval: 1100ms
    window: 1100ms
    active: true

bluetooth_proxy:
  active: true
```

Closed 2022-12-18.

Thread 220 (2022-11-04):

No issue, just a huge THANK YOU!!!!

RobertoCravallo, 2022-11-04:
I have been dabbling in HA for a couple of weeks now and am truly impressed! I even bought a powerfox to read my electricity meter. Good hard- and software, really bad data return timing!! So back it went. Stumbled over GLOW!! Hey, I am 66 years young, but I was stumped at first. Never have I tried something like this. Took a while, but I got it up and running. In the how too's, not everything is covered. But I got it up and running!!! Thank you for your work on this and sharing it with us!!!

Regards from Mannheim, Germany

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

klaasnicolaas, 2022-11-04:
Glad to hear you're happy with it.

Could you possibly explain what you think hasn't been covered yet? Because there is always room for improvement. Also funny that you tried the Powerfox before, I wanted to make another integration for that.

./Klaas

RobertoCravallo, 2022-11-04:
> funny that you tried the Powerfox before, I wanted to make another integration for that.
> ./Klaas
Do not bother!! It does work but the hard- and software are very good. powerfox sends data to Berlin and then it is supposed to come back in real time, so you can use it. I'm guessing the powerfox server does not handle all the data to well. I thought I messed up, but it worked early mornings and late at night!!! Once in a while during the day also!!! I have sent it back. Your solution is MUCH better and without depending on anyone!!

I will write up which problems I had to get it to work a bit later. Have to make lunch for my wife now... ;-)

RobertoCravallo, 2022-11-05:
Problems with realizing GLOW project!

First of all, I am 66 years old and have been around computers for the last 30 years. Who still remembers CLIPPER or DELPHI? I did all right there!!!

So after the data return from powerfox was TOTALLY unreliable, I decided to try my luck with GLOW. I am the type of person, that does not give up, once started!!

Until about three weeks ago, I had never heard of HOME ASSISTANT or ESP32!! ESP32 about a week ago!! I read as much as I could find on the net and ordered the parts from AMAZON. Touch cheaper in China, but I was ready to try this, otherwise I would have kept the powerfox, as it did record the data and only had problems in real time.

Ok so flashed GLOW via your cool WEB based flash and downloaded the yaml.

First problem: Where exactly to put the yaml. After a while, I "discovered" the default yaml. This seems to get overwritten on updating GLOW. So I had to change the 'pulse_rate' back to 10.000 and recompile after the update

klaasnicolaas, 2022-11-05:
> I did not install the extra LED and was very surprised, that the ESP32 board itself makes for a nice light show!!! Not mentioned anywhere. See attached foto, light is shining through the case.

I think this is the power LED of the ESP.

> To flash I had to press one of the buttons on the ESP32

This depends on the type of ESP32 board you use, my experience is that this is not necessary.

> Where exactly to put the yaml?

When you use ESP Webtools it is not necessary to also place the YAML config separately in ESPHome, you can adjust things via the ESPHome UI. I still have to adjust the documentation for that because a lot has changed and there are many different ways to install the firmware on an ESP.

> GPIO12, GPIO4 and GPIO5 have a strange "error" message that I did not understand.

The GPIO pin errors are a known problem, I'm currently testing with other pins and I think one of these days I will change these as default.

Anyway, thanks for your input, I'm going to change some things 😄

RobertoCravallo, 2022-11-05:
> I think this is the power LED of the ESP.
Might be the red one, but it has a second light that blinks intermittently.

> This depends on the type of ESP32 board you use, my experience is that this is not necessary.
Seems to be common though, as that was how it was portrayed on the site I found the info.

> The GPIO pin errors are a known problem,
GPIO16 seems a good bet, at least in the infos I found.

Gladly I will check / test things, if you need someone to do this!

RobertoCravallo, 2022-11-05:
Could it be, that the powerfox can do this? They offer a model that goes to the front of the meter, the one I had ordered was attached to the top and read the data through the hole in the top.

The one for the front can't work differently than GLOW, or can it?

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

klaasnicolaas, 2022-11-05:
I'm not familiar with how powerfox reads this at the top, so can't say how much that is the same or different to how the glow does that.

Closed 2022-12-13.

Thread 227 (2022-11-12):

NodeMCUv3 - cannot connect to WiFi - ESPHome is not working

teargas666, 2022-11-12:
Hi,

I have a problem with using Glow in my Home Asisstant.
I uploaded it to my ESP8266 NodeMCUv3, but I cannot connect it to WiFi. Below is my Code used in that project.

> # Home Assistant Glow
#
# Read your electricity meter by means of the pulse LED on your
# meter, useful if you do not have a serial port (P1).
#
substitutions:
  device_name: ha-glow-uterum
  friendly_name: uterum
  device_description: "Measure your energy consumption with the pulse LED on your smart meter"
  pulse_pin: GPIO12
  status_led: GPIO5
  # imp/kWh rate ⬇ #
  pulse_rate: '1000'
esphome:
  name: '${device_name}'
  comment: '${device_description}'
  project:
    name: "klaasnicolaas.home_assistant_glow"
    version: "2.0.1"
  platform: ESP8266
  board: nodemcuv2
wifi:
  ssid: 'ssid'
  password: 'password'
  # Enable fallback hotspot (captive portal) in case wifi connection fails
  ap:
    ssid: 'Asus_7C_Ogrodowa'
    password: wifi_password
captive_portal:
# Enable logging
logger:
# Enable Home Assistant API
api:
  password: esphome_api_password
ota:
  safe_mode: true
  reboot_timeout: 10min
  num_attempts: 5
web_server:
  port: 80
  auth:
    username: esphome_web_username
    password: esphome_web_password
output:
  # - platform: gpio
  #   pin: GPIO5
  #   id: output_blue
  - platform: gpio
    pin: GPIO2
    id: output_red
  - platform: gpio
    pin: GPIO4
    id: output_green
light:
  - platform: binary
    internal: true
    id: led_red
    name: Red
    output: output_red
# Status LED for connection
status_led:
  pin:
    # Blue LED
    number: ${status_led}
# Sensors for ESP version and WIFI information
text_sensor:
  - platform: version
    hide_timestamp: true
    name: "${friendly_name} - ESPHome Version"
  - platform: wifi_info
    ip_address:
      name: "${friendly_name} - IP Address"
      icon: mdi:wifi
    ssid:
      name: "${friendly_name} - Connected SSID"
      icon: mdi:wifi-strength-2
sensor:
  - platform: pulse_meter
    name: '${friendly_name} - Power consumption'
    unit_of_measurement: 'W'
    state_class: measurement
    device_class: power
    icon: mdi:flash-outline
    accuracy_decimals: 0
    pin: ${pulse_pin}
    # internal_filter: 100ms
    on_value:
      then:
        - light.turn_on:
            id: led_red
        - delay: 0.5s
        - light.turn_off:
            id: led_red
    filters:
      # multiply value = (60 / imp value) * 1000
      # - multiply: 60
      - lambda: return x * ((60.0 / ${pulse_rate}) * 1000.0);
    total:
      name: '${friendly_name} - Total energy'
      unit_of_measurement: 'kWh'
      icon: mdi:circle-slice-3
      state_class: total_increasing
      device_class: energy
      accuracy_decimals: 3
      filters:
        # multiply value = 1 / imp value
        # - multiply: 0.001
        - lambda: return x * (1.0 / ${pulse_rate});

klaasnicolaas, 2022-11-12:
I don't think it's really useful to throw your wifi credentials on github. See that you are still using an old version of the Home Assistant Glow.

What's in your logs?

teargas666, 2022-11-13:
I've removed it from my post.

I downloaded it from your github

After changing the board it's started to work.

Closed 2022-12-21.

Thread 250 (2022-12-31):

3.1.0 - Change default pulse pin

hank-droid, 2022-12-31:
Hi,
I started tinkering with this around 1y ago.
I was getting readings in the region of millions, so I parked it until I could print a case, which happened just now.
after powering it with a powerbank, it got connected and I added it in HA via the self discovery (the HA installation is different form the one when i originally installed glow).
I was still getting high readings, so I installed espohome addon to adopt the device in order to add the interval filter.
the glow was adopted, and I have then updated it.

now I no longer get any reading.

any suggestion on what i might have done wrong?

the diode seems to work because the  green led is flashing as picks up light, and i see it flashing differently depending on the sensitivity setting.
the blue led that used to flash on the esp32 does not.

thanks!

hank-droid, 2022-12-31:
ok I read the changelog and I reverted to the previous gpio pin (12) for sensor and it works. it also seems to have adjusted the rate and seems to be working properly overall!

hank-droid, 2023-01-05:
https://github.com/klaasnicolaas/home-assistant-glow/commit/a09da8f54f993d3239ff113a6e70d7def3b5ebee

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

klaasnicolaas, 2023-01-05:
The problem is that there is a difference between the version on the ESPHome webtools site and the yaml file in the repository. The pulse pin change is part of version 4.0.0 and has not yet been "released".

hank-droid, 2023-01-05:
I am not sure how I ended there… just leaving those thoughts here in case they can help someone else troubleshoot.

klaasnicolaas, 2023-01-05:
If you update the Home Assistant Glow in ESPHome, it automatically takes the latest version of the YAML file in this repository, while this is actually more of a development version. It would be better if it looked at the versions associated with a release tag in Github.

This has to be improved, can be improved, but I still have to find out how this can be improved in the field of CI.

Helmasynti, 2023-01-06:
@klaasnicolaas, maybe I don't quite understand what you mean but I downloaded the yaml from here

https://github.com/klaasnicolaas/home-assistant-glow/blob/main/home_assistant_glow.yaml

and the pulse pin change is there.

It's not a big deal to edit it, but since I am a total novice when it comes to microcontrollers and I built the system more than a year ago, I had forgotten many of the details of how everything was installed etc. It took me an effort to repair the system. Of course, the work was not in vain since now I understand the system better, but it was annoying and a bit scary to realise the system not working after the update. I believe that I am not the only novice around here hence the request to open the issue.

klaasnicolaas, 2023-01-06:
That the yaml file you link to in the main branch is a "development version" and therefore contains (breaking) changes that have not yet been released, or documented in release notes. However the `dashboard_import_url` currently automatically grabs the version from the main branch.

Actually, this is the latest stable version: https://github.com/klaasnicolaas/home-assistant-glow/blob/v3.1.0/home_assistant_glow.yaml

MPJK77, 2023-01-07:
Hi Klaas,

Today I started with the homeassistant glow project, nice work!
The "Get started" link from your github [https://github.com/klaasnicolaas/home-assistant-glow#get-started] brings us to project version "3.1.0" and refers to pulse_pin: GPIO13.

The link you posted in your reaction above yesterday (with v3.1.0 in it) brings us to project version "3.0.0" and refers to pulse_pin: GPIO12.

I am a little bit lost, which one should I use?

I have installed project version "3.1.0" and connected the photodiode to GPIO13 but I have some strange readings in HA.

In the photo and movie you posted on your github there are four wires going to the photodiode,
but in the visual schema there are only three wires to the photodiode?
I asume there should be only three wires conform the visual schema: 3v3, gnd, DO, is that wright?

Thank you in advance!

Gr. Maarten

MPJK77, 2023-01-07:
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

klaasnicolaas, 2023-01-07:
Understand that it is a bit unclear now and I want to improve that soon. The default branch will be `dev` and `main` a separate branch where I will only merge a stable release into, which I hope will make a better separation and should also be better for those who use updates via the ESPHome web tools.

> The link you posted in your reaction above yesterday (with v3.1.0 in it) brings us to project version "3.0.0" and refers to pulse_pin: GPIO12.

That was a mistake on my part because I had not updated the version in the yaml file itself, in this case the version as tagged with a release is leading. The use of GPIO13 is part of the 4.0.0 release, 3.1.0 still uses GPIO12. If you want to run stable then you should look [here](https://github.com/klaasnicolaas/home-assistant-glow/tree/v3.1.0), if you still want to work with the development version then [here](https://github.com/klaasnicolaas/home-assistant-glow/blob/main/home_assistant_glow.yaml).

> I asume there should be only three wires conform the visual schema: 3v3, gnd, DO, is that wright?

It is true that I have 4 wires going into the photodiode, but A0 is an empty wire that is not used, so in this case also use the schematic shown in the readme.

klaasnicolaas, 2023-01-07:
FYI, I made some changes to the repository that allow for a better separation between what is stable (main branch) and what is development (dev branch). I have also reverted the main branch to how it should be according to the 3.1.0 release and you will therefore continue to use GPIO12 as long as 4.0.0 has not yet been released.

MPJK77, 2023-01-08:
Hi klaas,

Thank you for your work, it is all clear to me now!

klaasnicolaas, 2024-02-12:
Close this issue since v4 is here and the default pulse pin has been changed for ESP32.

Closed 2024-02-12.

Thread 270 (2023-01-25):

Daily Energy v. Total Energy

droopycool, 2023-01-25:
Hi, I managed everything working and I think it's great. My only issue is that the "Total Energy" values are not matching the "Daily Energy" ones.

Total energy matches perfectly with the consumption my meter shows, Daily Energy seems to be growing at a much faster rate and not matching or even proportional to the total energy.

Attached my code (at least the part I think it's relevant) and some captures of the values. Can anybody help me to spot where the issue is?

```

  # Pulse meter
  - platform: pulse_meter
    name: '${friendly_name} - Power Consumption'
    id: sensor_energy_pulse_meter
    unit_of_measurement: 'W'
    state_class: measurement
    device_class: power
    icon: mdi:flash-outline
    accuracy_decimals: 0
    pin: ${pulse_pin}
    #internal_filter: 100ms
    on_value:
      then:
        - light.turn_on:
            id: led_red
        - delay: 0.5s
        - light.turn_off:
            id: led_red
    filters:
      # multiply value = (60 / imp value) * 1000
      # - multiply: 60
      - lambda: return x * ((60.0 / id(select_pulse_rate).state) * 1000.0);
    total:
      name: '${friendly_name} - Total Energy'
      id: sensor_total_energy
      unit_of_measurement: 'kWh'
      icon: mdi:circle-slice-7
      state_class: total_increasing
      device_class: energy
      accuracy_decimals: 3
      filters:
        # multiply value = 1 / imp value
        # - multiply: 0.001
        - lambda: return x * (1.0 / id(select_pulse_rate).state);
  # Total day useage
  - platform: total_daily_energy
    name: '${friendly_name} - Daily Energy'
    id: sensor_total_daily_energy
    power_id: sensor_energy_pulse_meter
    unit_of_measurement: 'kWh'
    icon: mdi:circle-slice-3
    state_class: total_increasing
    device_class: energy
    accuracy_decimals: 3
    filters:
      # Multiplication factor from W to kW is 0.001
      - multiply: 0.001

# Enable time component to reset energy at midnight
# https://esphome.io/components/time/homeassistant.html
time:
  - platform: homeassistant
    id: homeassistant_time

```

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

klaasnicolaas, 2023-01-25:
I think it's a distorted view because your total entity already had a value at midnight (what was the value at that time?), then it might be correct.

droopycool, 2023-01-26:
> I think it's a distorted view because your total entity already had a value at midnight (what was the value at that time?), then it might be correct.

To check if we are in the same page: if I take a measurement for total entity at any time of the day minues the value at midnight it should be the same as daily energy, right? It's not working like that for me:

Total Energy @ 00:00: 33.74 KWh
Daily Energy @ 00:00: 0 KWh

Total Energy @ 10:00: 41.06 KWh
Daily Energy @ 10:00: 33.78 KWh

ΔTotal Energy: 7.32 KWh
ΔDaily Energy: 33.78 KWh

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

klaasnicolaas, 2023-01-31:
I do see what you mean now, has it improved in the meantime?

droopycool, 2023-02-08:
Thanks for the comments. I checked with the logged consumption and the actual meter and I could not detect any power spikes. Also, after it ran several days values started to increase at a similar rate (still not as expected but better).

I reset the ESP32 and started from scratch with new names/entities and have been monitoring for the last 4 days, then both values report the same rate. I suspect that wonky values while setting up for the first time adjusting LED sensitivity could be the culprit here. Either way, thanks for the ideas and support!

Closed 2023-02-08.

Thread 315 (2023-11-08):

Firmware stuck on v2023.2.4

cieska, 2023-11-08:
Hi,

I have no experience with ESP32, but I'm just smart enough to make it work with home-assistant-glow. And it was running fine not counting the fact that on my system it stuck with the firmware version 2023.2.4 and it is not upgrading any more as it is now. I'm upgrading the home assistant occasionally, and other components, but only have an issue with HA-glow.
Any ideas?
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

cieska, 2023-11-08:
Just today I updated the config, as I though it may change anything, but no.

klaasnicolaas, 2023-11-09:
Try updating inside the ESPHome add-on, then you would also see the build logs. Perhaps it contains interesting information about why things go wrong.

cieska, 2023-11-09:
I'm a bit unsure how this must be done, I mean updating inside the ESPHome add-on. But I guess I go to ESPhome >> 3dot menu >> Install >> Choose the way to connect/install to the device.

So far I have got the first error
```
Updating /config/esphome/home-assistant-glow.yaml
------------------------------------------------------------

INFO ESPHome 2023.10.6
INFO Reading configuration /config/esphome/home-assistant-glow.yaml...
WARNING GPIO2 is a Strapping PIN and should be avoided.
Attaching external pullup/down resistors to strapping pins can cause unexpected failures.
See https://esphome.io/guides/faq.html#why-am-i-getting-a-warning-about-strapping-pins
WARNING GPIO5 is a Strapping PIN and should be avoided.
Attaching external pullup/down resistors to strapping pins can cause unexpected failures.
See https://esphome.io/guides/faq.html#why-am-i-getting-a-warning-about-strapping-pins
INFO Detected timezone 'Europe/London'
INFO Generating C++ source...
INFO Compiling app...
Processing home-assistant-glow (board: esp32dev; framework: arduino; platform: platformio/espressif32@5.4.0)
--------------------------------------------------------------------------------
HARDWARE: ESP32 240MHz, 320KB RAM, 4MB Flash
 - toolchain-xtensa-esp32 @ 8.4.0+2021r2-patch5
Dependency Graph
|-- AsyncTCP-esphome @ 2.0.1
|-- WiFi @ 2.0.0
|-- FS @ 2.0.0
|-- Update @ 2.0.0
|-- ESPAsyncWebServer-esphome @ 3.1.0
|-- DNSServer @ 2.0.0
|-- ESPmDNS @ 2.0.0
|-- ArduinoJson @ 6.18.5
|-- Improv @ 1.2.3
|-- noise-c @ 0.1.4
Compiling .pioenvs/home-assistant-glow/src/main.cpp.o
Linking .pioenvs/home-assistant-glow/firmware.elf
RAM:   [=         ]  12.6% (used 41212 bytes from 327680 bytes)
Flash: [=====     ]  54.6% (used 1002653 bytes from 1835008 bytes)
Building .pioenvs/home-assistant-glow/firmware.bin
Creating esp32 image...
Successfully created esp32 image.
esp32_create_combined_bin([".pioenvs/home-assistant-glow/firmware.bin"], [".pioenvs/home-assistant-glow/firmware.elf"])
Wrote 0x106330 bytes to file /data/build/home-assistant-glow/.pioenvs/home-assistant-glow/firmware-factory.bin, ready to flash to offset 0x0
========================= [SUCCESS] Took 77.42 seconds =========================
INFO Successfully compiled program.
INFO Resolving IP address of home-assistant-glow.local
INFO  -> 192.168.0.64
INFO Uploading /data/build/home-assistant-glow/.pioenvs/home-assistant-glow/firmware.bin (1008432 bytes)
ERROR ESP requests password, but no password given!
===== [ERROR] /config/esphome/home-assistant-glow.yaml =====

======================== [SUMMARY] ========================
  - /config/esphome/home-assistant-glow.yaml: FAILED
```
Then after chasing YAML errors, I'm stuck with having short some sort of credentials

```
Updating /config/esphome/home-assistant-glow.yaml
------------------------------------------------------------

INFO ESPHome 2023.10.6
INFO Reading configuration /config/esphome/home-assistant-glow.yaml...
WARNING GPIO2 is a Strapping PIN and should be avoided.
Attaching external pullup/down resistors to strapping pins can cause unexpected failures.
See https://esphome.io/guides/faq.html#why-am-i-getting-a-warning-about-strapping-pins
WARNING GPIO5 is a Strapping PIN and should be avoided.
Attaching external pullup/down resistors to strapping pins can cause unexpected failures.
See https://esphome.io/guides/faq.html#why-am-i-getting-a-warning-about-strapping-pins
INFO Detected timezone 'Europe/London'
INFO Generating C++ source...
INFO Compiling app...
Processing home-assistant-glow (board: esp32dev; framework: arduino; platform: platformio/espressif32@5.4.0)
--------------------------------------------------------------------------------
HARDWARE: ESP32 240MHz, 320KB RAM, 4MB Flash
 - toolchain-xtensa-esp32 @ 8.4.0+2021r2-patch5
Dependency Graph
|-- AsyncTCP-esphome @ 2.0.1
|-- WiFi @ 2.0.0
|-- FS @ 2.0.0
|-- Update @ 2.0.0
|-- ESPAsyncWebServer-esphome @ 3.1.0
|-- DNSServer @ 2.0.0
|-- ESPmDNS @ 2.0.0
|-- ArduinoJson @ 6.18.5
|-- Improv @ 1.2.3
|-- noise-c @ 0.1.4
Compiling .pioenvs/home-assistant-glow/src/main.cpp.o
Linking .pioenvs/home-assistant-glow/firmware.elf
RAM:   [=         ]  12.6% (used 41212 bytes from 327680 bytes)
Flash: [=====     ]  54.6% (used 1002653 bytes from 1835008 bytes)
Building .pioenvs/home-assistant-glow/firmware.bin
Creating esp32 image...
Successfully created esp32 image.
esp32_create_combined_bin([".pioenvs/home-assistant-glow/firmware.bin"], [".pioenvs/home-assistant-glow/firmware.elf"])
Wrote 0x106330 bytes to file /data/build/home-assistant-glow/.pioenvs/home-assistant-glow/firmware-factory.bin, ready to flash to offset 0x0
========================= [SUCCESS] Took 77.42 seconds =========================
INFO Successfully compiled program.
INFO Resolving IP address of home-assistant-glow.local
INFO  -> 192.168.0.64
INFO Uploading /data/build/home-assistant-glow/.pioenvs/home-assistant-glow/firmware.bin (1008432 bytes)
ERROR ESP requests password, but no password given!
===== [ERROR] /config/esphome/home-assistant-glow.yaml =====

======================== [SUMMARY] ========================
  - /config/esphome/home-assistant-glow.yaml: FAILED
```
What kind of passwords?

klaasnicolaas, 2023-11-15:
These refer to your secrets file with all your passwords for ESPHome, you can also remove this and replace it with something yourself

Closed 2023-12-24.

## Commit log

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2021-07-28 ✨ Add the Home Assistant Glow files
    [ESP Bottom-side.stl, ESP Top-side.stl, Sensor Bottom-side.stl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]
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2021-08-06 Update home_assistant_glow.yaml (#6)
    * Update home_assistant_glow.yaml
    - Use W to bring in line with https://developers.home-assistant.io/docs/core/entity/sensor/#available-device-classes
    - add `state_class` and `device_class` to `pulse_meter` sensor so the power consumption can be used in Statistics Graph Card, not just total usage.
    * Update home_assistant_glow.yaml
    * :pencil2: Update the version
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2021-08-16 Configuring the pulse rate on top (#26)
    * 📚 Update the documentation
    * 📚 Small improvements on the docs
    * 🔨 Configure the imp/kWh rate on top
    * 📚 Small change on docs
    * 📚 Small text change
    * 📚 Small change on text
    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
2021-09-15 Added some details on the large batch of faulty diodes that seem to currently be out there as per https://github.com/klaasnicolaas/home-assistant-glow/issues/34 (#43)
2021-09-15 📚 Update the documentation (#50)
    * Fix the url
    * Fix url
    * Fix the url (final)
    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
2021-10-26 update Readme.md (#72)
    * update Readme.md
    * Update Readme.md #committing suggestions
    adding the suggestions you provided 👍🏽
    * Update Readme.md #committing suggestions -2
    * Update Readme.md
    I believe this resolves all the changes you requested for .... thank you for letting me contribute to your project ....hopefully next year i'll make a more valuable contribution🤞🏽🤞🏽😄
    * Update Readme.md
    * Update Readme.md
2021-11-20 ✨ Create a GH pages website (#90)
    * 🚚 Move images to the static directory
    * Auto build firmware and gh-pages website
    * Change it to publish workflow
    * Add some information
    * Change naming in the CI workflow
    * Replace !secrets for substitutions
    * Comment out the wifi credentials
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2022-01-01 Add daily energy sensor (#101)
    * ✨ Add daily energy sensor
    * Update id
    * Bump version
2022-01-01 Add buttons to the Glow! (#106)
    * Add buttons for restart and total reset
    * Change the API reset service (breaking)
    * Add sensor for wifi signal strength
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2022-02-07 Rename the case files (#130)
    [ESP32_bottom_side_v1.stl, ESP32_top_side_v1.stl, Sensor_bottom_side_v1.stl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]
2022-03-10 Migrate to new Core Configuration (#141)
    according to https://esphome.io/components/esphome.html the recommended core-configuration is now split into
    esphome and esp32 (https://esphome.io/components/esp32.html) or esp8266 (https://esphome.io/components/esp8266.html)
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2022-03-14 Change the used time platform (#145)
    * Change to homeassistant as default time platform
    * 📚 Add extra information in the FAQ
2022-05-06 📚 Update on the documentation (#168)
    * Update affiliate urls
    * Add a disclaimer
2022-08-23 Add visual schema to documentation (#196)
    * Add schema files
    * Update the documentation
    [schema.fzz]
2022-11-12 Change default pulse pin (#228)
    * Move defining pins to substitutions
    * Move to GPIO13 for the pulse pin
2022-11-12 Add 3D printing step file (#229)
    * Move stl's to new folder
    * Add the step file with info in docs
    [ESP32_bottom_side_v1.stl, ESP32_top_side_v1.stl, Home_Assistant_Glow.step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]
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2023-05-14 Add filters for reducing amount of data output (#95)
    * Add filters for reducing amount of data output
    This change adds commented-out samples of how to use filters to reduce the amount of data that are written to the HA recorder database by default.
    Depending on the `pulse_rate` variable, the type of house/apartment and the heating system in use, this may or may not be a problem in practice. For example, with the default in the file, `1000`, a power consumption of 3600 W means that the sensors produce 2 HA state changes per second (which means 7200 state changes per hour). With the commented-out filters enabled, only 396 state changes will be produced per hour.
    * Add documentation to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
2024-01-03 Split config for building firmware per board (#321)
    * Move to a split config for different boards
    * Build the firmware on a new way
    * Change to local packages import
2024-01-03 Add Docusaurus website (#323)
    * Move files to assets folder
    * Introduce a Docusaurus site for github pages
    * Update build workflow
    [schema.fzz]
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2024-01-11 Completion of information on docs website (#333)
    * Add introduction page
    * Add getting started docs page
    * Update sidebars and add configuration doc page
    * Add diagram page on reference category
    * Add hardware shopping table
    * Add instructions for firmware install and connect to HA
    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
    [ESP32_bottom_side_v1.stl, ESP32_top_side_v1.stl, Home_Assistant_Glow.step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]
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2024-01-19 contribute an esp32-wroom-32d case design (#368)
    * contribute an esp32-wroom-32d case design with included documentation and reference images
    * Update docs/docs/reference/cases.mdx
    * Update docs/docs/reference/cases.mdx
    * Update docs/docs/reference/cases.mdx
    * Update docs/docs/reference/cases.mdx
    * Update cases.mdx to include a URL to a persistent link to enable anonymous access and viewing.
    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
    [ESP32-WROOM-32D_bottom_case.stl, ESP32-WROOM-32D_top_case.stl]
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2024-01-27 fix: re-uploaded the top case to correct error (#374)
    [ESP32-WROOM-32D_top_case.stl]
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2024-02-12 ⬆️ Update dependency esp-web-tools to v10 (#398)
    * ⬆️ Update dependency esp-web-tools to v10
    * Remove the NPM package and bump the version in script
    * Update renovate.json
    ---------
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2024-03-13 Update the FAQ for using the filter from pulse_meter (#418)
    * Update the FAQ for using the filter from pulse_meter
    * Remove double quotes
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2024-04-03 🔄 synced file(s) with klaasnicolaas/github-config (#444)
    * 🔄 synced local '.github/release-drafter.yml' with remote 'github/release-drafter.yml'
    * 🔄 synced local '.github/labels.yml' with remote 'github/labels.yml'
    * 🔄 synced local '.github/FUNDING.yml' with remote 'github/FUNDING.yml'
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2024-06-29 ⬆️ Update klaasnicolaas/action-pr-labels action to v2 (#512)
    * ⬆️ Update klaasnicolaas/action-pr-labels action to v2
    * Remove optional parameters for pr labels action
    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
2024-08-26 ⬆️ Update esphome/build-action action to v4 (#559)
    * ⬆️ Update esphome/build-action action to v4
    * Change variable inputs for ESPHome build action
    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
2024-10-24 Refactor renaming guide for Home Assistant Glow device (#631)
    * Refactor renaming guide for Home Assistant Glow device
    * Improve clarity and detail
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2025-01-31 ⬆️ Update esphome/build-action action to v6 (#704)
    * ⬆️ Update esphome/build-action action to v6
    * Remove caching from build-firmware workflow
    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
2025-07-26 fix: update broken link to 3D-printed case resources in README (#782)
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2026-01-17 feat: Update ESP32 config to use esp-idf and variant (#880)
    * feat: Update ESP32 config to use esp-idf and variant
    * fix: update minimum version requirement to 2025.11.0 in esp8266.yaml
2026-01-17 feat: Add ESP32-C3 configuration for Home Assistant Glow (#881)
    * feat: Add ESP32C3 configuration for Home Assistant Glow
    * fix: Update device description and GPIO pin configuration for ESP32-C3
    * feat: Update docs to include ESP32-C3 in hardware and GPIO pinout sections
2026-01-17 docs: Add FAQ about encryption key + general docs update (#882)
    * chore: Update images in documentation for better clarity and organization
    * fix: Update documentation to replace references from ESPHome Compiler to ESPHome Dashboard
    * docs: Add warnings about firmware management when adopting devices in ESPHome Dashboard
    * feat: Add FAQ entry about the encryption key
    * fix: Update docs to replace references from ESPHome Dashboard to ESPHome Builder
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2026-06-07 Add configurable pulse meter internal filter (#992)
    * feat: Add configurable internal filter for pulse meter
    * feat: Increase max pulse rate and update internal filter documentation
    * fix: Correct link title for pulse meter in firmware documentation
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2026-10-20 ⬆️ Update actions/setup-node action to v7.1.0 (#1054)
    * ⬆️ Update actions/setup-node action to v7.1.0
    * Fix spacing before setup-node version comment
    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
2026-11-02 ⬆️ Update actions/download-artifact action to v8.0.2 (#1051)
    * ⬆️ Update actions/download-artifact action to v8.0.2
    * Fix YAML comment spacing for download-artifact pins
    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
